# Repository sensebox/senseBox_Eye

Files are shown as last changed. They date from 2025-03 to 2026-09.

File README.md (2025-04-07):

# senseBox Eye
## /examples
Some basic examples to test functionality of the MCU. If youre interested in the AI capabilities of the board you can check out this [image classifier](https://github.com/PaulaScharf/senseBox_Eye-edge_impulse) that I created using edge-impulse.

## /hardware
Contains datasheets and schematics.

## /BSP
Contains configuration for the board support package (which have to be included into the [Arduino core for the ESP32](https://github.com/espressif/arduino-esp32)), UF2 bootloader and circuit python bootloader.

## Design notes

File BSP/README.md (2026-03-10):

Our module is the "ESP32-S3-WROOM-1-N16R8" which has 16MB flash (Quad SPI) and 8MB PSRAM (Octal SPI) on top of 512KB SRAM.

## [arduino-esp32 core](https://github.com/espressif/arduino-esp32)
- `boards.txt` (only contains the segment relevant for senseBox Eye)
- the folder `arduino`

## platformio/espressif32
- the folder `platformio`

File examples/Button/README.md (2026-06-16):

### Pinout
```cpp
#define SW_BUTTON   21
#define BOOT_BUTTON 0
```

# Examples
### sw-button
Print to serial when the "SW"-button is pressed.

### sw-button
Print to serial when the Boot-button is pressed.

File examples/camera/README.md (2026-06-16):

### Pinout
```cpp
#define PWDN_GPIO_NUM  46
#define RESET_GPIO_NUM -1
#define XCLK_GPIO_NUM  15
#define SIOD_GPIO_NUM  4
#define SIOC_GPIO_NUM  5

#define Y9_GPIO_NUM    16 // D7
#define Y8_GPIO_NUM    17 // D6
#define Y7_GPIO_NUM    18 // D5
#define Y6_GPIO_NUM    12 // D4
#define Y5_GPIO_NUM    10 // D3
#define Y4_GPIO_NUM    8  // D2
#define Y3_GPIO_NUM    9  // D1
#define Y2_GPIO_NUM    11 // D0
#define VSYNC_GPIO_NUM 6
#define HREF_GPIO_NUM  7
#define PCLK_GPIO_NUM  13
```

# Tested Camera models
The senseBox Eye comes with an OV2640. But its possible to attach other cameras that use the DVP too.

| model | max resolution | color type | output format | Len Size |
| --- | --- | --- | --- | --- |
| OV2640  | 1600 x 1200 | color | YUV(422/420)/YCbCr422<br>RGB565/555<br>8-bit compressed data<br>8/10-bit Raw RGB data | 1/4" |
| OV7725  | 640 x 480 | color | Raw RGB<br/>GRB 422<br/>RGB565/555/444<br/>YCbCr 422 | 1/4" |
| OV5640  | 2592 x 1944 | color | RAW RGB<br/>RGB565/555/444<br/>CCIR656<br/>YUV422/420<br/>YCbCr422<br/>compression | 1/4" |

Depending on how much ram is already taken up by the rest of the script, the resolution of the camera might have to be reduced to prevent an overflow (additionally it also helps to set the fb_count of the config to 1 instead of higher numbers). So the max resolution can often not be achieved.

# Examples
### CameraWebServer
Default example from the esp32 BSP. Streams camera images over Wifi.

Requires version 3.0.7 of the BSP for face detection and recognition (newer versions dont include the model zoo anymore). Dont forget to adjust the Wifi credentials.

### CameraWebServer_EdgeImpulse
Same as CameraWebServer but with custom edge impulse model instead of face detection. Streaming is broken, only capturing single frames possible.

### camera-display
Continuously print current camera image on the display.

### camera-sd
Capture a single camera image (as JPEG) and save it to sd-card. Requires PSRAM turned on.

### ov7725
Continuously print current camera image on the display. If the "SW"-Button is pressed, capture a single camera image (as RGB565, because ov7725 doesnt natively support JPEG) and save it to sd-card. Requires PSRAM turned on. (Note: WIPES SD-CARD ON STARTUP)

### ov5640
Continuously print current camera image on the display. If the "SW"-Button is pressed, capture a single camera image (as RGB565, because ov5640 doesnt natively support JPEG) and save it to sd-card. The highest resolution achieved with this script is 2560x1600px (4.1MP). Requires PSRAM turned on. (Note: WIPES SD-CARD ON STARTUP)

# esp32-camera
The underlying camera driver used in these examples is [esp32-camera](https://github.com/espressif/esp32-camera). 

It supports the following resolution shorthands:
| key | resolution |
|---|---|
| FRAMESIZE_96X96 | 96x96 |
| FRAMESIZE_QQVGA | 160x120 |
| FRAMESIZE_128X128  | 128x128 |
| FRAMESIZE_QCIF | 176x144 |
| FRAMESIZE_HQVGA | 240x176 |
| FRAMESIZE_240X240  | 240x240 |
| FRAMESIZE_QVGA | 320x240 |
| FRAMESIZE_320X320  | 320x320 |
| FRAMESIZE_CIF | 400x296 |
| FRAMESIZE_HVGA | 480x320 |
| FRAMESIZE_VGA | 640x480 |
| FRAMESIZE_SVGA | 800x600 |
| FRAMESIZE_XGA | 1024x768 |
| FRAMESIZE_HD | 1280x720 |
| FRAMESIZE_SXGA | 1280x1024 |
| FRAMESIZE_UXGA | 1600x1200 |
| **--- 3MP Sensors ---** | 
| FRAMESIZE_FHD | 1920x1080 |
| FRAMESIZE_P_HD | 720x1280 |
| FRAMESIZE_P_3MP | 864x1536 |
| FRAMESIZE_QXGA | 2048x1536 |
| **--- 5MP Sensors ---** |
| FRAMESIZE_QHD | 2560x1440 |
| FRAMESIZE_WQXGA | 2560x1600 |
| FRAMESIZE_P_FHD | 1080x1920 |
| FRAMESIZE_QSXGA | 2560x1920 |
| FRAMESIZE_5MP | 2592x1944 |

The following formats are supported:
| key | pixel format |
|---|---|
| PIXFORMAT_RGB565 | 2BPP / RGB565 |
| PIXFORMAT_YUV422 | 2BPP / YUV422 |
| PIXFORMAT_YUV420 | 1.5BPP / YUV420 |
| PIXFORMAT_GRAYSCALE  | 1BPP / Grayscale |
| PIXFORMAT_JPEG | JPEG / Compressed |
| PIXFORMAT_RGB888 | 3BPP / RGB888 |
| PIXFORMAT_RAW | RAW |
| PIXFORMAT_RGB444 | 3BP2P / RGB444 |
| PIXFORMAT_RGB555 | 3BP2P / RGB555 |

The driver also supports a multitude of camera settings for image capture ([tutorial](https://randomnerdtutorials.com/esp32-cam-ov2640-camera-settings/)).

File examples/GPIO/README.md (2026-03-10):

### Pinout
```cpp
#define IO14 14
#define IO48 48
```

# QWIIC interface
### of the senseBox Eye
```
-4--IO14
-3--IO48
-2--3v3
-1--GND
```

### of the LED-Matrix
```
-4--LED
-3--
-2--3v3
-1--GND
```

### of the water temperature sensor
```
-4--
-3--temperature
-2--3v3
-1--GND
```

### of the soil moisture sensor (smt50)
```
-4--moisture
-3--temperature
-2--3v3
-1--GND
```

# Examples
### analog
Read analog input and print it to serial.

### smt50
Print soil temperature to serial.

### led-matrix
Display a guy with a hat on the LED-matrix.

### scale
Print measured weight using the HX711 to serial.

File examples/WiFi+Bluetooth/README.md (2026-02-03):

The ESP32S3 chip includes both WiFi and Bluetooth functionality. Attach the included antenna to use it. Without the antenna the board might get damaged and the signal strength is drastically reduced.

# Examples
### mac-address
Example script from the ESP32 BSP to print the mac addresses of the MCU to serial.

### wifi-hotspot
Create an access point and host a small website there.

### wifi-connect
Connect to a WiFi access point and continuously print the signal strength. Values can range between 0 (good) and -120 (bad). If the signal is lost try to reconnect.

### ble
Create a service and characteristic and then send and receive values through that characteristics. Can be tested with the "nRF Connect" app for example. 

### openSenseMap
Send data from an HDC1080 sensor to a device on the openSenseMap.

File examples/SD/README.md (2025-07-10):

### Pinout
```cpp
#define VSPI_MISO   40 // DAT
#define VSPI_MOSI   38 // CMD
#define VSPI_SCLK   39 // SCK/CLK
#define VSPI_SS     41 // CS
#define SD_ENABLE   3
#define SD_SW       42 // card detect pin (LOW = card inserted)
```

# Examples
### sd-card-basics
Test basic sd-card functionality and print results to serial.

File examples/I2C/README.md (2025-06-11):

### Pinout
```cpp
#define PIN_QWIIC_SDA 2
#define PIN_QWIIC_SCL 1

Wire.begin(PIN_QWIIC_SDA,PIN_QWIIC_SCL);
```
These pins are both used by the I2C QWIIC interface and the integrated battery sensor (max17048).

# Examples
### i2c-scanner
Standard I2C Scanner based on [this](https://playground.arduino.cc/Main/I2cScanner/).

### vl53l8cx
Print closest distance from vl53l8cx in serial monitor (based on code generated from blockly).

### display
Print the senseBox-bike loading animation and a QR-Code on the display.

### hdc1080
Print temperature and humidity to serial.

### mpu6050
Print acceleration, gyro and temperature to serial.

### sps30
Print PM1.0, PM2.5, PM4.0 and PM10 to serial.

### max17048
Print battery charge measurements from the onboard max17048 sensor to serial and display.

### i2c-chain
Combines display, vl53l8cx, hdc1080, mpu6050 and sps30. Draws the sensor measurements on the display and prints the loop times to serial.

### vl53l8cx-led-matrix
Display distances recorded by the vl53l8cx on the LED-matrix

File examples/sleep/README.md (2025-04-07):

[see sleep mode documentation](https://docs.espressif.com/projects/esp-idf/en/stable/esp32/api-reference/system/sleep_modes.html)

# Examples
### deep-sleep
Go to deep sleep for 2 seconds. Code taken from [here](https://randomnerdtutorials.com/esp32-deep-sleep-arduino-ide-wake-up-sources/).

### light-sleep
Go to light-sleep for 2 seconds, wake up for 2 seconds, go to light-sleep for 2 seconds and so on.

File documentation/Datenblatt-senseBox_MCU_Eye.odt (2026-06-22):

### Datenblatt für die senseBox MCU Eye

#### Allgemeine Informationen

- Modell: senseBox MCU Eye
- Hersteller: Reedu GmbH & Co. KG
- Plattform: Arduino-kompatibel
- Einsatzbereiche: Bildung, Citizen Science, Forschung, Umweltüberwachung, Smart City Anwendungen, Bildverarbeitung, Maschinelles Lernen

#### Technische Spezifikationen

##### Mikrocontroller

- Mikrocontroller: ESP32-S3 (Xtensa LX7 Dual-Core)
- Architektur: 32-Bit
- Taktfrequenz: Bis zu 240 MHz
- Flash-Speicher: 16 MB
- PSRAM: 8 MB
- EEPROM: Emuliert im Flash-Speicher

##### Stromversorgung

- Betriebsspannung: 5V
- Stromversorgung:
  - USB: 5V über USB-C-Anschluss, auch zur Programmierung und Kommunikation
  - Extern: 5V über den VIN-Pin (empfohlene externe Stromquelle: 5V DC)
  - Maximale Spannung: 5V (Achtung: Überschreiten kann die Platine beschädigen)
- Stromaufnahme:
  - Im Durchschnitt ca. 80 mA, abhängig von der aktiven Peripherie und dem Modus (WiFi, Bluetooth)

##### Schnittstellen

- Digitale I/O-Pins: 4 (davon werden standardmäßig 2 als I2C Schnittstelle genutzt)
  - PWM-Pins: Alle digitalen Pins können als PWM-Ausgänge konfiguriert werden
  - Maximaler Strom pro I/O-Pin: 40 mA
- Analoge Eingänge: 4 (12-Bit Auflösung)
  - Analoge Eingangsbereiche: 0 bis 3.3V
- Kommunikationsschnittstellen:
  - I2C: 1 Schnittstelle (fest zugewiesen auf IO2 (SDA) und IO1 (SCL))
- USB: USB-C-Anschluss für Programmierung, Datenübertragung und Stromversorgung
- DVP Kamera Anschluss: Kompatibel mit OV2640 (und ähnlichen Kameras)
- MicroSD-Karten-Slot: Für externe Datenspeicherung (SDIO-Modus)

##### Erweiterungsanschlüsse und Sensor-Integration

- QWIIC-Steckverbinder: Mehrere Ports zur einfachen Integration von Sensoren und -Aktoren (Stecktyp: JST-SH)
- Kompatibilität: Unterstützt diverse Sensoren
- Pin-Kompatibilität: 3.3V kompatibel (die Pins sind nicht 5V tolerant)

##### Physische Eigenschaften

- Abmessungen: 60 mm x 30 mm x 10 mm (L x B x H)
- Gewicht: Ca. 10 Gramm
- Betriebstemperaturbereich: -40°C bis 65°C

##### Eingebettete Funktionen

- Bootloader: Arduino-kompatibel, ermöglicht einfache Programmierung über die Arduino-IDE und andere Entwicklungsumgebungen wie ESP-IDF
- ADC: 12-Bit A/D-Wandler für analoge Eingänge, ermöglicht präzise Messungen
- Low-Power-Modus: Verschiedene Energiesparmodi, um den Stromverbrauch zu minimieren

#### Anwendungsbereiche

- Bildung: Ideal für den Unterricht in Elektronik, Programmierung, Maschinellem Lernen und Umweltsensorik, inklusive praktischer Projekte und Experimente
- Citizen Science: Ermöglicht Bürgerwissenschaftlern, Umweltdaten zu sammeln und zu analysieren, z.B. Luftqualität, Wetterdaten
- Umweltüberwachung: In stationären und mobilen Umweltsensorplattformen zur Überwachung von Temperatur, Luftfeuchtigkeit, Licht, UV-Strahlung und mehr
- Forschung: Unterstützt wissenschaftliche Projekte durch präzise Datenerfassung und flexible Integration von Sensoren und Aktoren
- Smart City: Integration in Smart City Projekte zur Überwachung von Umweltparametern, Verkehrsdaten und zur Steuerung städtischer Infrastrukturen
- Bildverarbeitung: Eignet sich für Projekte im Bereich der computergestützten Bildanalyse.

#### Sicherheits- und Nutzungsrichtlinien

- Elektrische Sicherheit:
  - Maximale Eingangsspannung: Vin-Pin nicht über 5V versorgen, da die Pins nur für 3.3V ausgelegt sind
  - Kurzschlussvermeidung: Vorsichtiger Umgang mit den Pins und Verbindungen zur Vermeidung von Kurzschlüssen
- Wärmemanagement:
  - Belüftung: Sorgen Sie für ausreichende Kühlung und Belüftung, insbesondere bei hoher Rechenlast oder Außeneinsatz bei hohen Temperaturen.
- Umgang mit empfindlichen Komponenten:
  - Elektrostatische Entladung (ESD): Verwenden Sie antistatische Armbänder und ESD-Schutzmatten beim Umgang mit der Platine, um Beschädigungen zu vermeiden.
- Umweltschutz:
  - Feuchtigkeitsschutz: Vermeiden Sie den Einsatz in extrem feuchten Umgebungen oder unter Wasser ohne entsprechende Schutzgehäuse.

#### Verpackung und Lieferung

- Lieferumfang: senseBox MCU Eye, OV2640
- Verpackung: Antistatische Verpackung zum Schutz vor elektrostatischen Entladungen, robuste Verpackung für sicheren Transport

#### Hinweise und Empfehlungen

- Software & Programmierung:
  - Arduino IDE: Unterstützt die Entwicklung von Anwendungen mit ESP-IDF und der Arduino-IDE, inklusive Bibliotheken für Sensoren und Aktoren
  - Online-Ressourcen: Umfangreiche Dokumentation, Tutorials und Forenbeiträge sind verfügbar, um Benutzer bei der Entwicklung und Implementierung von Projekten zu unterstützen
- Erweiterungsmöglichkeiten:
  - Sensoren: Breite Palette an kompatiblen Sensoren und Aktoren verfügbar, z.B. für Wetterüberwachung, Luftqualität, Wassersensorik
  - Kommunikationsmodule: WiFi, Bluetooth, & LoRa integriert

Hinweis: Dieses Datenblatt bietet eine umfassende Übersicht über die technischen Spezifikationen, Funktionen und Anwendungsmöglichkeiten der senseBox MCU Eye. Für spezifische Anwendungen und detaillierte technische Informationen wird empfohlen, die vollständige technische Dokumentation sowie die Benutzerhandbücher zu konsultieren.

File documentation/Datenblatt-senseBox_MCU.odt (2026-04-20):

### Datenblatt für die senseBox MCU

#### Allgemeine Informationen

- Modell: senseBox MCU
- Hersteller: senseBox
- Plattform: Arduino-kompatibel
- Einsatzbereiche: Bildung, Citizen Science, Forschung, Umweltüberwachung, Smart City Anwendungen

#### Technische Spezifikationen

##### Mikrocontroller

- Mikrocontroller: Atmel ATmega2560
- Architektur: 8-Bit AVR RISC
- Taktfrequenz: 16 MHz
- Flash-Speicher: 256 KB (8 KB reserviert für den Bootloader)
- SRAM: 8 KB
- EEPROM: 4 KB

##### Stromversorgung

- Betriebsspannung: 5V (Versorgungsspannung für alle Pins)
- Stromversorgung:
  - USB: 5V über USB-B-Anschluss, auch zur Programmierung und Kommunikation
  - Extern: 7-12V über DC-Netzteilanschluss (Barrel Jack) oder Vin-Pin
  - Maximale Spannung: 20V (Achtung: Überschreiten kann die Platine beschädigen)
- Stromaufnahme:
  - Abhängig von der Anzahl und Art der angeschlossenen Komponenten und Sensoren

##### Schnittstellen

- Digitale I/O-Pins: 54, davon 15 als PWM-Ausgänge nutzbar
  - PWM-Pins: 2 bis 13, 44 bis 46
  - Maximaler Strom pro I/O-Pin: 40 mA
  - Maximaler Strom für alle I/O-Pins zusammen: 200 mA
- Analoge Eingänge: 16 (10-Bit Auflösung)
  - Analoge Eingangsbereiche: 0 bis 5V (Standard), einstellbar auf 1.1V (interner Referenzspannung) oder externe Referenz
  - Analoge Referenzspannung: AREF Pin für externe Referenzspannungen
- Kommunikationsschnittstellen:
  - UART: 4 serielle Schnittstellen für serielle Kommunikation (Serial, Serial1, Serial2, Serial3)
  - I2C: 1 Schnittstelle (fest zugewiesen auf A4 (SDA) und A5 (SCL))
  - SPI: 1 Schnittstelle (fest zugewiesen auf digitalen Pins 50 (MISO), 51 (MOSI), 52 (SCK), 53 (SS))
- USB: USB-B-Anschluss für Programmierung und serielle Kommunikation, Unterstützung von USB 2.0
- SD-Karten-Slot: MicroSD-Kartenleser für externe Datenspeicherung (SDIO-Modus)

##### Erweiterungsanschlüsse und Sensor-Integration

- Grove-Steckverbinder: Mehrere Ports für den einfachen Anschluss von Grove-Sensoren und -Aktoren (z.B. Grove Temperature & Humidity Sensor, Grove Air Quality Sensor)
- Kompatibilität: Unterstützt Arduino Shields, die für den Mega 2560 Formfaktor ausgelegt sind, z.B. Ethernet Shield, WiFi Shield, GSM Shield

##### Physische Eigenschaften

- Abmessungen: 84 mm x 55 mm x 12 mm (L x B x H)
- Gewicht: Ca. 35 Gramm
- Betriebstemperaturbereich: 0°C bis 70°C
- Lagerungstemperaturbereich: -20°C bis 85°C

##### Eingebettete Funktionen

- Bootloader: Arduino-kompatibel, ermöglicht einfache Programmierung über die Arduino-IDE und USB-Verbindung
- RTC: Optional über Zusatzmodule (Real Time Clock) zur Zeitstempelung von Daten
- Watchdog-Timer: Integriert, um das System bei Fehlfunktionen neu zu starten und erhöhte Systemsicherheit zu gewährleisten
- ADC: 10-Bit A/D-Wandler für analoge Eingänge, ermöglicht präzise Messungen

#### Anwendungsbereiche

- Bildung: Ideal für den Unterricht in Elektronik, Programmierung und Umweltsensorik, inklusive praktischer Projekte und Experimente
- Citizen Science: Ermöglicht Bürgerwissenschaftlern, Umweltdaten zu sammeln und zu analysieren, z.B. Luftqualität, Wetterdaten
- Umweltüberwachung: In stationären und mobilen Umweltsensorplattformen zur Überwachung von Temperatur, Luftfeuchtigkeit, Licht, UV-Strahlung und mehr
- Forschung: Unterstützt wissenschaftliche Projekte durch präzise Datenerfassung und flexible Integration von Sensoren und Aktoren
- Smart City: Integration in Smart City Projekte zur Überwachung von Umweltparametern, Verkehrsdaten und zur Steuerung städtischer Infrastrukturen

#### Sicherheits- und Nutzungsrichtlinien

- Elektrische Sicherheit:
  - Überspannungsschutz: Vermeiden Sie Spannungen über 12V an den Vin-Pin, um Schäden an der Hardware zu vermeiden.
  - Kurzschlussvermeidung: Stellen Sie sicher, dass keine Kurzschlüsse zwischen den I/O-Pins und anderen leitenden Materialien auftreten.
- Wärmemanagement:
  - Belüftung: Sorgen Sie für ausreichende Belüftung, insbesondere bei hoher Stromaufnahme oder Außeneinsatz bei hohen Temperaturen.
- Umgang mit empfindlichen Komponenten:
  - Elektrostatische Entladung (ESD): Verwenden Sie antistatische Armbänder und ESD-Schutzmatten beim Umgang mit der Platine, um Beschädigungen zu vermeiden.
- Umweltschutz:
  - Feuchtigkeitsschutz: Vermeiden Sie den Einsatz in extrem feuchten Umgebungen oder unter Wasser ohne entsprechende Schutzgehäuse.

#### Verpackung und Lieferung

- Lieferumfang: senseBox MCU-Platine, USB-Kabel, Schnellstartanleitung
- Verpackung: Antistatische Verpackung zum Schutz vor elektrostatischen Entladungen, robuste Verpackung für sicheren Transport

#### Hinweise und Empfehlungen

- Software & Programmierung:
  - Arduino IDE: Unterstützt die Entwicklung von Anwendungen mit der Arduino-IDE, inklusive Bibliotheken für Sensoren und Aktoren
  - Online-Ressourcen: Umfangreiche Dokumentation, Tutorials und Forenbeiträge sind verfügbar, um Benutzer bei der Entwicklung und Implementierung von Projekten zu unterstützen
- Erweiterungsmöglichkeiten:
  - Sensoren: Breite Palette an kompatiblen Sensoren und Aktoren verfügbar, z.B. für Wetterüberwachung, Luftqualität, Wassersensorik
  - Kommunikationsmodule: Unterstützung für WiFi, Bluetooth, GSM, LoRa durch Zusatzmodule und Shields

Hinweis: Dieses Datenblatt bietet eine umfassende Übersicht über die technischen Spezifikationen, Funktionen und Anwendungsmöglichkeiten der senseBox MCU. Für spezifische Anwendungen und detaillierte technische Informationen wird empfohlen, die vollständige technische Dokumentation sowie die Benutzerhandbücher zu konsultieren.

### Anwendungsbeispiel: Überwachung der Luftqualität in städtischen Gebieten ohne Gassensor

#### Projektziel

Das Ziel dieses Projekts ist die Überwachung der Luftqualität in einem städtischen Gebiet, insbesondere durch die Erfassung von Feinstaubkonzentrationen (PM2.5 und PM10), Temperatur, Luftfeuchtigkeit und Luftdruck. Dies soll dazu beitragen, Umwelt- und Gesundheitsinformationen für die Bevölkerung bereitzustellen und datenbasierte Entscheidungen zu unterstützen.

#### Komponenten und Ausstattung

- senseBox MCU: Zentrale Steuerungseinheit zur Datenerfassung und -verarbeitung.
- Feinstaubsensor (z.B. SDS011): Misst die Konzentration von Feinstaubpartikeln (PM2.5 und PM10) in der Luft.
- Temperatur- und Luftfeuchtigkeitssensor (z.B. HDC1080): Erfasst die Umgebungstemperatur und relative Luftfeuchtigkeit.
- Luftdrucksensor (z.B. DPS310): Misst den atmosphärischen Luftdruck.
- Grove-Verbindungskabel: Zur einfachen Verbindung der Sensoren mit der senseBox MCU.
- MicroSD-Karte: Zur Speicherung der gesammelten Daten.
- Optional: WLAN-Modul (z.B. ESP8266): Ermöglicht die drahtlose Übertragung der Daten an eine zentrale Datenbank oder Cloud.

#### Projektaufbau

1. Installation und Montage:
  - Die senseBox MCU und die Sensoren werden in einem wetterfesten Gehäuse montiert und an einem repräsentativen Ort im städtischen Gebiet installiert. Orte mit hohem Verkehrsaufkommen oder in der Nähe von Industriegebieten sind besonders relevant.
2. Sensorintegration und Kalibrierung:
  - Die Sensoren werden über Grove-Kabel an die senseBox MCU angeschlossen. Die Programmierung erfolgt mithilfe der Arduino-IDE unter Verwendung spezifischer Bibliotheken für die Sensoren.
  - Eine Kalibrierung der Sensoren, insbesondere des Feinstaubsensors, wird durchgeführt, um genaue und zuverlässige Messungen zu gewährleisten.
3. Datenaufzeichnung und -speicherung:
  - Die erfassten Daten (PM2.5, PM10, Temperatur, Luftfeuchtigkeit, Luftdruck) werden in regelmäßigen Intervallen (z.B. alle 5 Minuten) auf der MicroSD-Karte gespeichert. Die Speicherung umfasst Zeitstempel, um die Datenanalyse zu ermöglichen.
  - Optional können die Daten zusätzlich über WLAN an eine zentrale Datenbank gesendet werden, um eine Echtzeitüberwachung zu ermöglichen.
4. Datenübertragung und -verarbeitung:
  - Bei Verwendung eines WLAN-Moduls werden die Daten kontinuierlich an einen Server übertragen, wo sie gespeichert und verarbeitet werden können.
  - Die Daten werden visualisiert, um die Entwicklung der Luftqualität über die Zeit hinweg darzustellen. Dies kann durch Diagramme, Tabellen oder interaktive Karten geschehen.
5. Öffentliche Information und Sensibilisierung:
  - Eine Webplattform oder eine mobile App kann eingerichtet werden, um die Öffentlichkeit über die aktuelle Luftqualität zu informieren. Wichtige Daten wie Feinstaubkonzentration, Temperatur und Luftdruck sind zugänglich.
  - Benachrichtigungen oder Warnungen werden ausgegeben, wenn bestimmte Schwellenwerte, insbesondere für Feinstaub, überschritten werden, um gesundheitliche Risiken zu kommunizieren.

#### Nutzen und Vorteile

- Gesundheitsförderung: Die Bevölkerung wird über die aktuelle Luftqualität informiert, was insbesondere für empfindliche Gruppen wie Kinder, ältere Menschen und Personen mit Atemwegserkrankungen wichtig ist.
- Datenbasierte Entscheidungen: Die erhobenen Daten unterstützen städtische Planer und Behörden bei der Entwicklung von Maßnahmen zur Verbesserung der Luftqualität, wie z.B. der Begrünung von Flächen oder der Verkehrsregulierung.
- Bildungszwecke: Die gesammelten Daten können in Schulen und Universitäten genutzt werden, um die Bedeutung von Umweltüberwachung und Luftqualität zu lehren.

#### Herausforderungen und Lösungen

- Datengenauigkeit: Um die Qualität der Daten sicherzustellen, müssen die Sensoren regelmäßig überprüft und gewartet werden. Kalibrierungsprozeduren sollten regelmäßig durchgeführt werden.
- Wetterbedingungen: Bei extremen Wetterbedingungen muss die senseBox in einem geeigneten Gehäuse geschützt werden, um die Sensoren vor Beschädigung zu schützen.

Dieses Anwendungsbeispiel zeigt, wie die senseBox MCU ohne Gassensoren effektiv zur Überwachung und Analyse der Luftqualität in städtischen Gebieten genutzt werden kann, um wichtige Umwelt- und Gesundheitsdaten bereitzustellen.

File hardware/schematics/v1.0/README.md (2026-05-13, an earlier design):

In these schematics the sd-card is missing the CS-Pin. The sd-card doesnt work.

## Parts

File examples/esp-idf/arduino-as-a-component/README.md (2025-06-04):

# arduino-as-a-component
The esp-idf allows to include the esp32-arduino framework. This allows one to use arduino libraries in the esp-idf. 

In this example the Adafruit Neopixel library is included. Once flashed, the RGB-LED onboard the senseBox Eye should go through a rainbow cycle of colors.

Before building you need to run the following commands in this folder:
```
mkdir -p components && \
cd components && \
git clone https://github.com/espressif/arduino-esp32.git arduino
```

The Adafruit_Neopixel library then has to be copied into `components/arduino/libraries`. The `components/arduino/CMakeLists.txt` now has to be adjusted. After the line `set(ARDUINO_ALL_LIBRARIES` add `Adafruit_NeoPixel`. Furthermore the following lines have to be added:
```
set(ARDUINO_LIBRARY_Adafruit_NeoPixel_SRCS libraries/Adafruit_NeoPixel/Adafruit_NeoPixel.cpp
  libraries/Adafruit_NeoPixel/esp.c 
  libraries/Adafruit_NeoPixel/esp8266.c 
  libraries/Adafruit_NeoPixel/kendyte_k210.c)
```
And lastly the includedirs have to be adjusted like so: `set(includedirs variants/${CONFIG_ARDUINO_VARIANT}/ cores/esp32/ ${ARDUINO_LIBRARIES_INCLUDEDIRS} libraries/Adafruit_NeoPixel)`.

When building I had problems with the i2c-slave (I fixed one line and commented another one out). I also had to make a tiny adjustment to the neopixel library code (the error message will tell you what to do).

[This wiki page](https://docs.espressif.com/projects/arduino-esp32/en/latest/esp-idf_component.html) gives more details about including arduino as a component.

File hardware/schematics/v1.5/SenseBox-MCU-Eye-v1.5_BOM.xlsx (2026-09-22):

 |  |  | senseBox MCU Eye v1.5
Item # | *Designator | *Qty | Manufacturer | *Mfg Part # | Description / Value | *Package/Footprint | Type | Your Instructions / Notes
1 | C1, C2, C4, C15, C16, C23, C24 | 7 |  | CL05A475MP5NRNC | CAP CER 4.7UF 10V X5R 0402 | C0402 | SMD
2 | C3, C5, C7, C8, C9, C10, C13, C14, C18, C19, C20, C21, C22, C29 | 14 |  | GRM155R71C104KA88D | CAP CER 100NF 16V X7R 0402 | C0402 | SMD
3 | C6 | 1 |  | GRM158R61A226ME15J | CAP CER 22UF 10V X5R 0402 | C0402 | SMD
4 | C11 | 1 |  | CL05A106MQ5NUNC | CAP CER 10UF 6.3V X5R 0402 | C0402 | SMD
5 | C12 | 1 |  | CL05A106MQ5NUNC | CAP CER 10UF 6.3V X5R 0402 | C0402 | SMD
6 | C17, C28 | 2 |  | GRM155R61C105KA12D | CAP CER 1UF 16V X5R 0402 | C0402 | SMD
7 | C25, C26, C27 | 3 |  | GRM155R61A225KE95D | CAP CER 2.2UF 10V X5R 0402 | C0402 | SMD
8 | C30, C31 | 2 |  | GRM21BR60J226ME39L | CAP CER 22UF 6.3V X5R 0805 | 0805N | SMD
9 | C32, C33 | 2 |  | GRM188R61A475KE15D | CAP CER 4.7UF 10V X5R 0603 | 0603N | SMD
10 | D1 | 1 | Worldsemi | WS2812B-2020 | Addressable RGB LED (integrated driver), 2020 package | WS2812_2020 | SMD
11 | D2 | 1 | Texas Instruments | LM66200DRLR | Ideal diode / power mux controller | SOT-5X3 | SMD
12 | D3 | 1 | Infineon Technologies | ESD5V3U2U-03F-E6327 | Uni-directional TVS/ESD protection diode, 5.3V, 0.4pF | SOT723 | SMD
13 | D4 | 1 |  | LTST-C190KRKT | LED, red, 0603 | 0603N | SMD
14 | D5, D6 | 2 |  | 1PS79SB40,115 | General-purpose Schottky diode, SOD523 | SOD523 | SMD
15 | D7 | 1 |  | LTST-C190KGKT | LED, green, 0603 | 0603N | SMD
16 | IC1 | 1 | Espressif Systems | ESP32-S3-WROOM-1-N16R8 | WiFi/BLE MCU module, 16MB flash / 8MB PSRAM | ESP32-S3-WROOM-1 | SMD
17 | IC2 | 1 | Amphenol Communications Solutions (FCI) | F34G-1A7Q1-E8C24 | FPC connector, right-angle SMD, 24-pos, 0.5mm pitch | WE-CHIP_FPC24-0.5-CAM | SMD
18 | IC3 | 1 | Microchip | MCP73831T-2ACI/OT | Li-Ion/Li-Po linear charge management controller | SOT23-5 | SMD
19 | IC4 | 1 |  | RFM95W-868S2 | LoRa transceiver module, 868MHz (SX1276) | RFM9X | SMD
20 | IC5 | 1 | Diodes Incorporated | AP2127N-2.8TRG1 | 150mA CMOS LDO regulator, 2.8V | SOT23 | SMD
21 | IC6 | 1 | Diodes Incorporated | AP2127N-1.5TRG1 | 150mA CMOS LDO regulator, 1.5V | SOT23 | SMD
22 | IC7 | 1 | Texas Instruments | REG710NA-5 | 150mA low-Iq LDO regulator, 5V | SOT23-6 | SMD
23 | IC8 | 1 | Analog Devices (Maxim) | MAX17048G+T10 | 1-cell fuel gauge IC, UDFN8 2x2mm | UDFN8_2020 | SMD
24 | IC9 | 1 | Richtek | RP602Z330C-E2-F | Buck converter IC, WLCSP | WLCSP-20-P1 | SMD
25 | IC10 | 1 | TDK InvenSense | ICM-20948 | 9-axis IMU (accel/gyro/mag), QFN24 3x3mm | QFN24-3X3 | SMD
26 | IC11 | 1 |  | AP2127N-1.8TRG1 | 150mA CMOS LDO regulator, 1.8V | SOT23 | SMD
27 | J1 | 1 | Hroparts | TYPE-C-31-M-12 | USB Type-C receptacle, 12-pin SMD | USB-C-S | SMD
28 | J2 | 1 |  | U.FL-R-SMT-1(10) | U.FL RF coax receptacle, PCB mount, 50 ohm | U.FL | SMD
29 | J3 | 1 | JST | S2B-PH-SM4-TB | 2-pos PH-series SMD header, top entry | JST_S2B-PH-SM4-TB | SMD
30 | J4, J6 | 2 | JST | SM04B-SRSS-TB | 4-pos SR-series SMD header, top entry | JST_SM04B-SRSS-TB | SMD
31 | J5 | 1 | JST | SM02B-SRSS-TB | 2-pos SR-series SMD header, top entry | JST_SM02B-SRSS-TB | SMD
32 | L2 | 1 |  | SRN5040TA-1R0M | INDUCTOR SHIELDED PWR 1UH SMD | 5040 | SMD
33 | Q2 | 1 | Nexperia | PMV48XP,215 | P-channel MOSFET, -20V | SOT23 | SMD
34 | R1, R13, R14 | 3 |  | RC0402FR-07100KL | RES 100K OHM 1% 0402 | C0402 | SMD
35 | R2, R3, R4, R37 | 4 |  | RC0402JR-070RL | RES 0 OHM JUMPER 0402 | C0402 | SMD
36 | R5, R6, R7, R15, R17, R20, R26, R27, R28, R29, R44, R45 | 12 |  | RC0402FR-0710KL | RES 10K OHM 1% 0402 | C0402 | SMD
37 | R8, R16, R33, R34 | 4 |  | RC0402FR-0733RL | RES 33 OHM 1% 0402 | C0402 | SMD
38 | R9, R10, R23, R24 | 4 |  | RC0402FR-074K7L | RES 4.7K OHM 1% 0402 | C0402 | SMD
39 | R11 | 1 |  | RC0402FR-072KL | RES 2K OHM 1% 0402 | C0402 | SMD
40 | R12, R18 | 2 |  | RC0402FR-071KL | RES 1K OHM 1% 0402 | C0402 | SMD
41 | R30, R31, R48, R50 | 4 |  | RC0402FR-075K1L | RES 5.1K OHM 1% 0402 | C0402 | SMD
42 | R39 | 1 |  | RC0402FR-07330RL | RES 330 OHM 1% 0402 | C0402 | SMD
43 | SD1 | 1 | Amphenol FCI | 10067099-400LF | microSD card socket, push-push | SD_47309XXXX | SMD
44 | SW1, SW2, SW3 | 3 | E-Switch | TL3305AF160QG | SMD tactile push-button switch, TL3305 series | TL3305 | SMD
45 | SW4 | 1 | Nidec Components | CUS-22TB | SMD slide switch, DPDT, 0.3A/4VDC | CUS22B | SMD
46 | T8 | 1 | Nexperia | BSS138PS,115 | N-channel MOSFET, 60V | SOT363 | SMD

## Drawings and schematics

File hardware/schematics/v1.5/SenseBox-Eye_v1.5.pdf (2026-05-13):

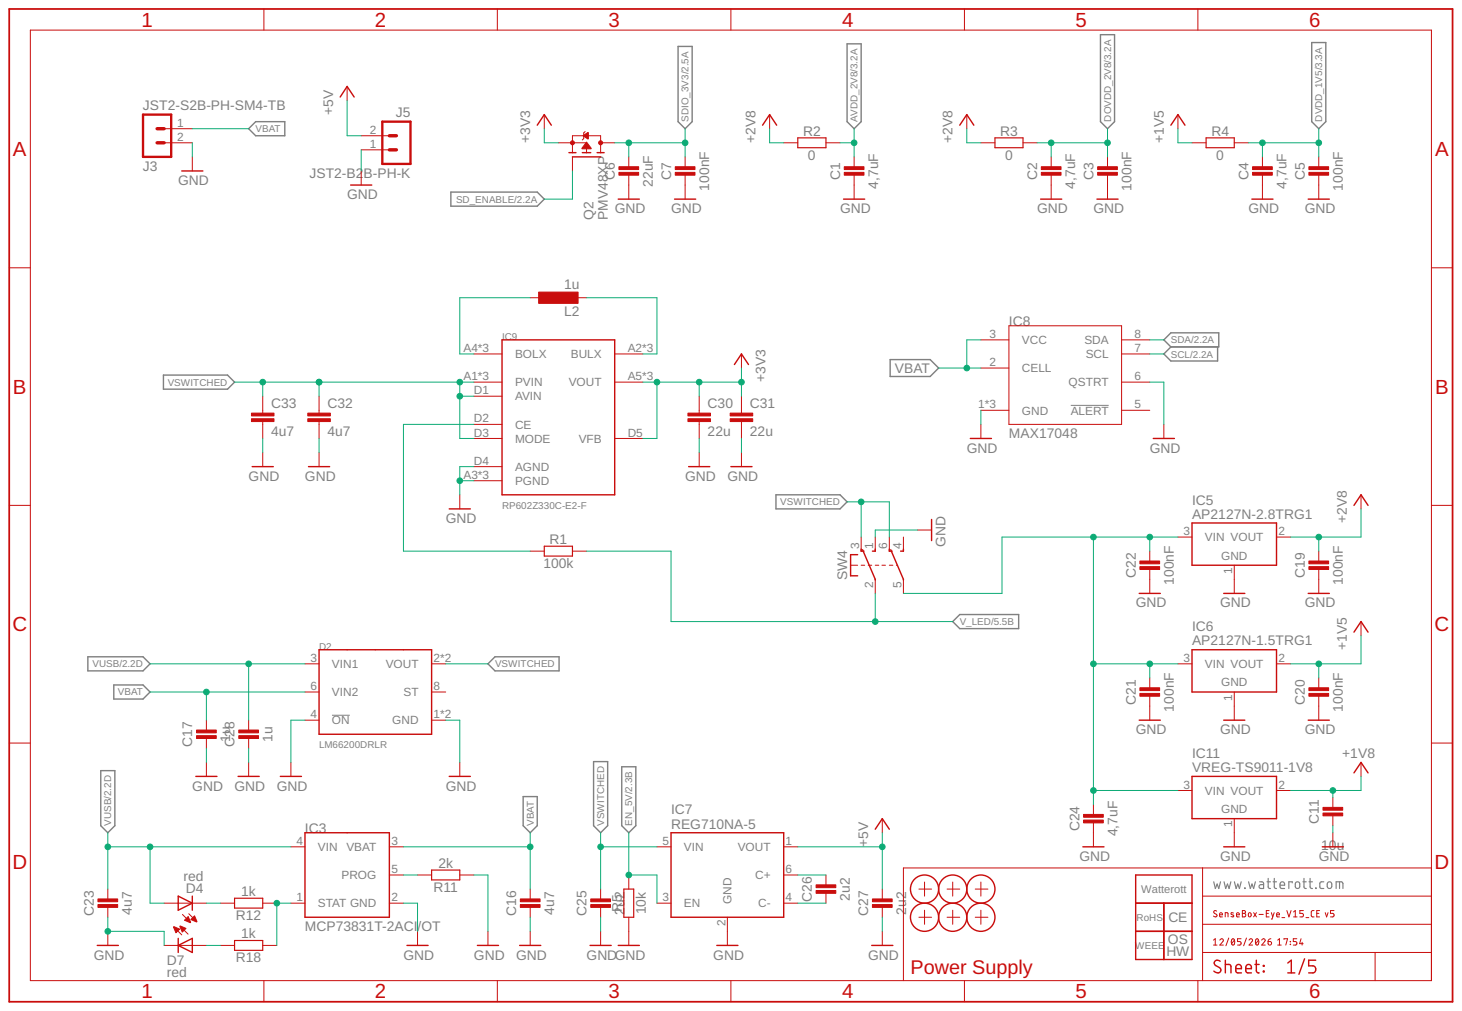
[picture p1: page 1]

red 1k | 2k

Power Supply

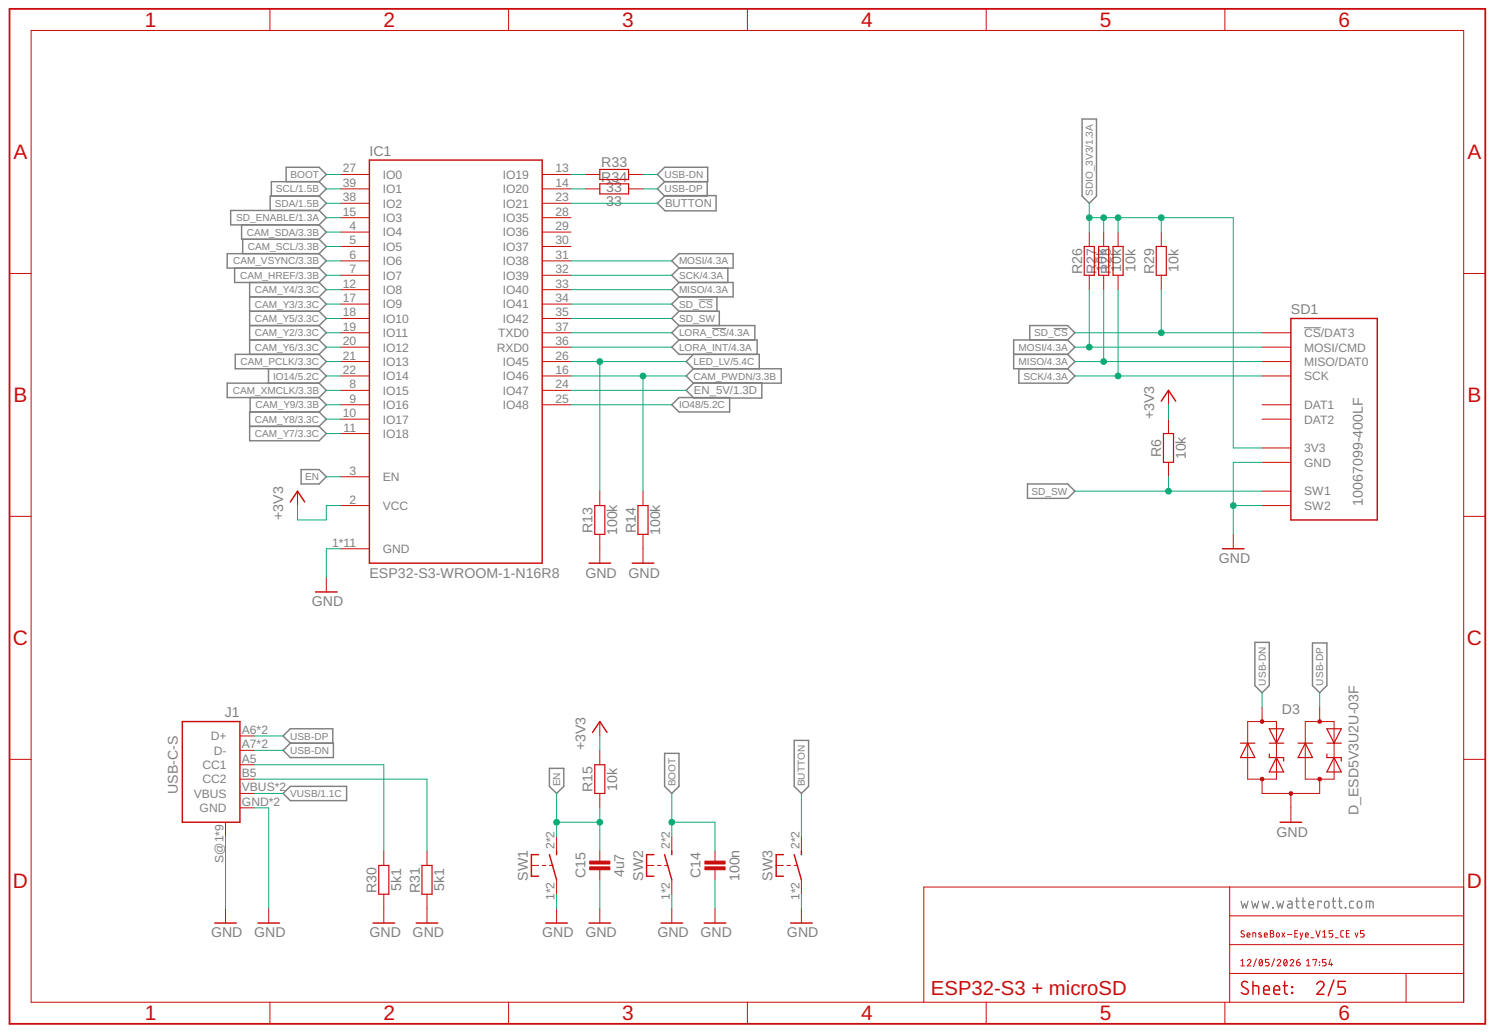
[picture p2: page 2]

10k 10k 10k 10k D_ESD5V3U2U-03F 5k1 5k1 GND GND GND GND 3333 100n 4u7 +3V3 GND GND GND GND GND GND GND GND 100k 100k GND GND 10k +3V3 10k +3V3 IC1 ESP32-S3-WROOM-1-N16R8 IO36 29 IO39 32 IO38 31 IO35 28 IO37 30 IO40 33 IO48 25 IO14 22 IO12 20 IO13 21 IO9 17 IO10 18 IO11 19 IO47 24 IO1 39 IO3 15 IO21 23 IO19 13 IO18 11 IO5 5 IO17 10 IO16 9 IO4 4 IO0 27 IO2 38 IO15 8 IO8 12 IO7 7 IO6 6 EN 3 VCC 2 GND 1*11 IO41 34 IO42 35 IO45 26 IO46 16 TXD0 37 RXD0 36 IO20 14 SD1 10067099-400LF DAT2 CS/DAT3 MOSI/CMD 3V3 SCK GND MISO/DAT0 DAT1 SW1 SW2 R26 R27 R28 R29 J1 USB-C-SD+ A6*2 D- A7*2 VBUS VBUS*2 GND GND*2 S@1*9 CC1 A5 CC2 B5 D3 R30 R31 R33 R34 C14 C15 SW3 1*2 2*2 SW1 1*2 2*2 SW2 1*2 2*2 R13 R14 R15 R6 CAM_SDA/3.3B CAM_SCL/3.3B CAM_HREF/3.3B CAM_Y4/3.3C CAM_Y3/3.3C CAM_Y5/3.3C CAM_Y2/3.3C CAM_Y6/3.3C CAM_PCLK/3.3C BUTTON BUTTON CAM_XMCLK/3.3B CAM_Y9/3.3B CAM_Y8/3.3C CAM_Y7/3.3C CAM_PWDN/3.3B SD_ENABLE/1.3A SCL/1.5B CAM_VSYNC/3.3B MOSI/4.3A MOSI/4.3A MISO/4.3A MISO/4.3A SCK/4.3A SCK/4.3A SDIO_3V3/1.3A SD_CS SD_CS USB-DP USB-DP USB-DP USB-DN USB-DN USB-DN VUSB/1.1C LORA_CS/4.3A LORA_INT/4.3A BOOT BOOTEN EN SDA/1.5B LED_LV/5.4C SD_SW SD_SW IO14/5.2C IO48/5.2C EN_5V/1.3D ESP32-S3 + microSD ABCD 1 2 3 4 5 6 ABCD 1 2 3 4 5 6

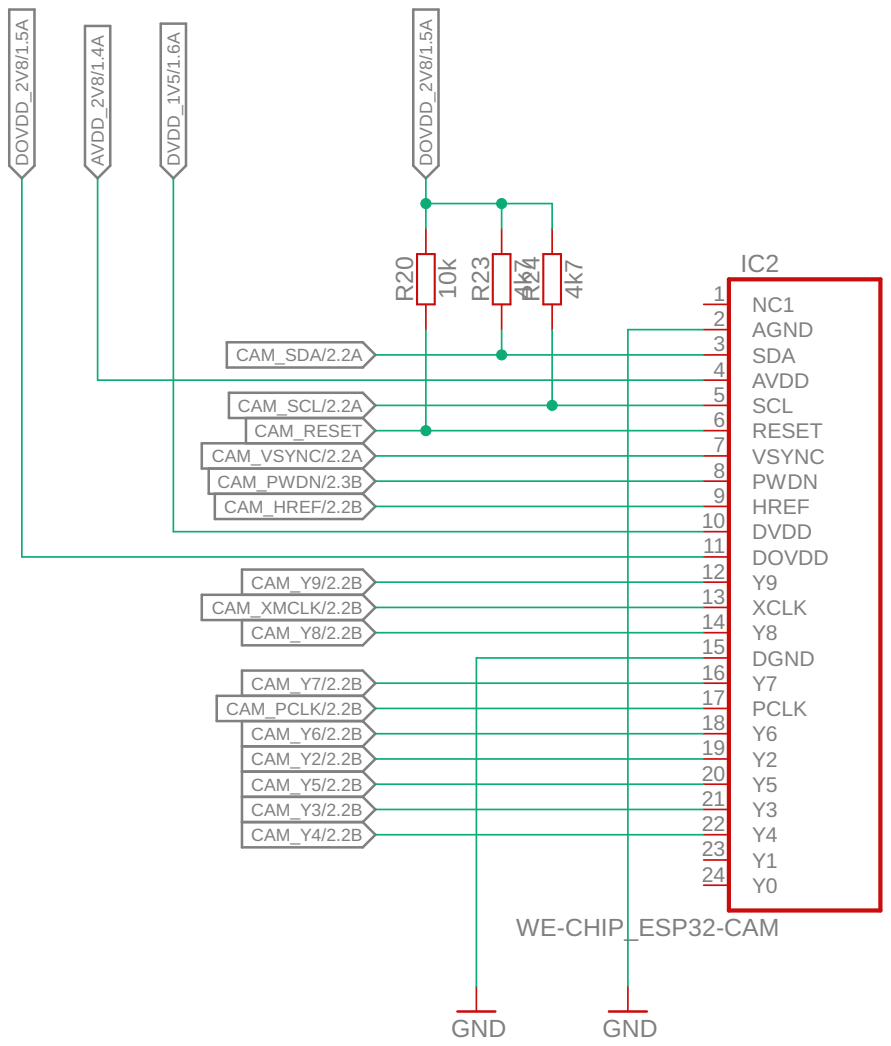
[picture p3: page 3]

10k 4k7 4k7 GND GND WE-CHIP_ESP32-CAM R20 R23 R24IC2AGND 2 AVDD 4 DGND 15 DOVDD 11 DVDD 10 HREF 9 NC1 1 PCLK 17 PWDN 8 RESET 6 SCL 5 SDA 3 VSYNC 7 XCLK 13 Y0 24 Y1 23 Y2 19 Y3 21 Y4 22 Y5 20 Y6 18 Y7 16 Y8 14 Y9 12 CAM_SDA/2.2A CAM_SCL/2.2A AVDD_2V8/1.4A CAM_RESET CAM_VSYNC/2.2A CAM_PWDN/2.3B CAM_HREF/2.2B DVDD_1V5/1.6A CAM_Y9/2.2B CAM_XMCLK/2.2B CAM_Y8/2.2B CAM_Y7/2.2B CAM_Y6/2.2B CAM_Y2/2.2B CAM_Y5/2.2B CAM_Y3/2.2B CAM_Y4/2.2B DOVDD_2V8/1.5A DOVDD_2V8/1.5A CAM_PCLK/2.2B Kamera ABCD 1 2 3 4 5 6 ABCD 1 2 3 4 5 6

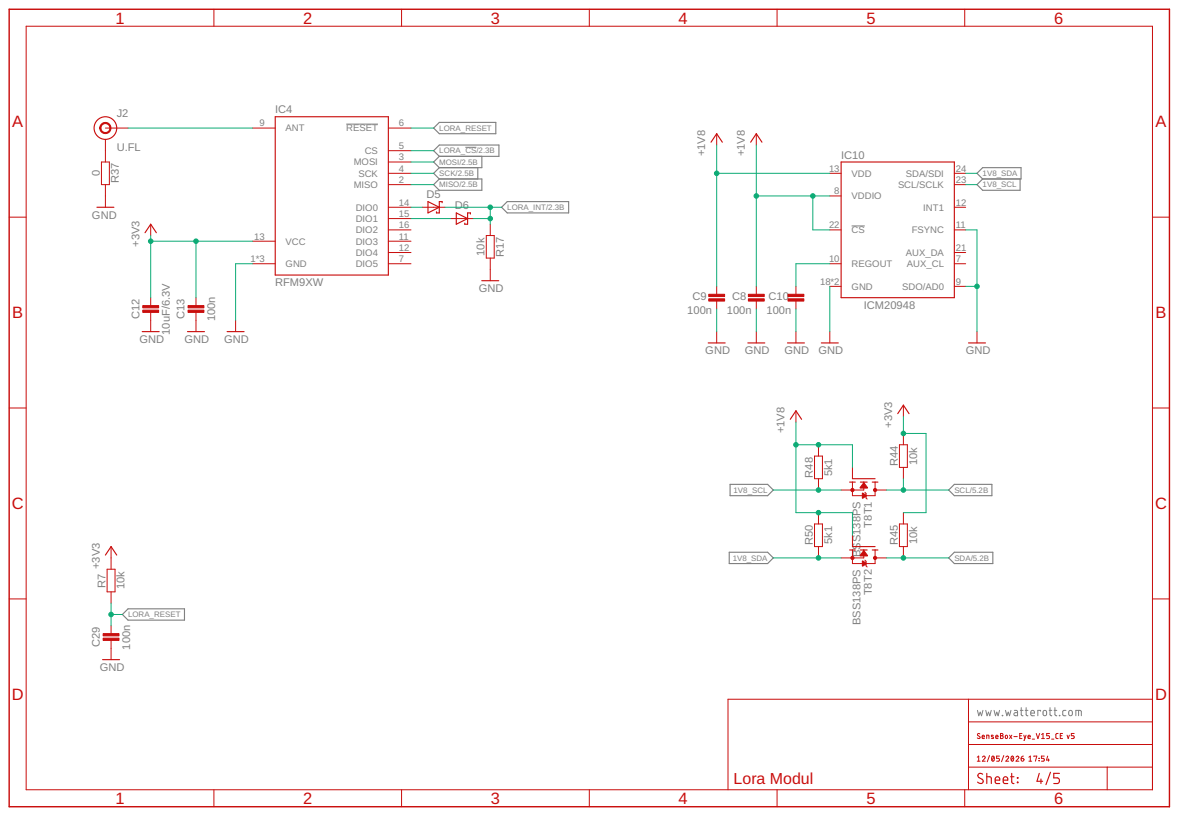
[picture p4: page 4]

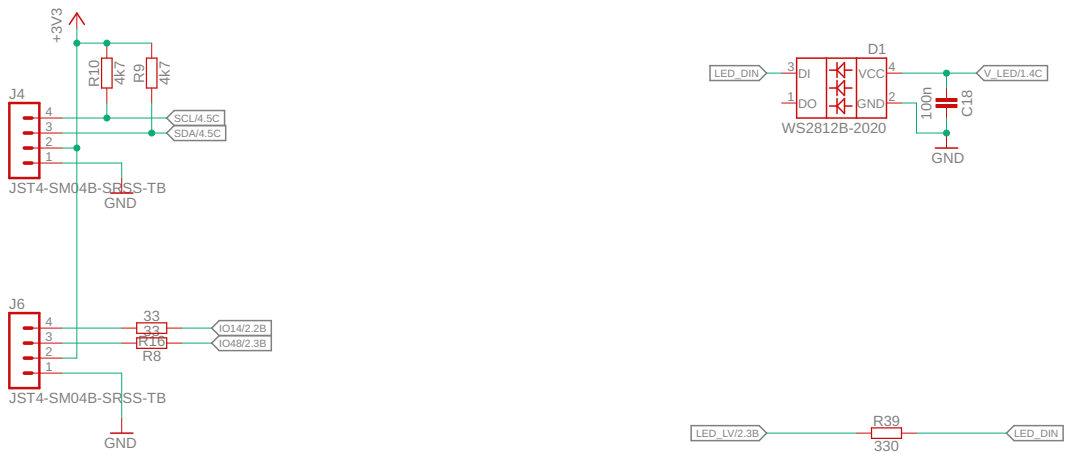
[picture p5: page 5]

33 | IO14/2.2B
R16 | IO48/2.3B

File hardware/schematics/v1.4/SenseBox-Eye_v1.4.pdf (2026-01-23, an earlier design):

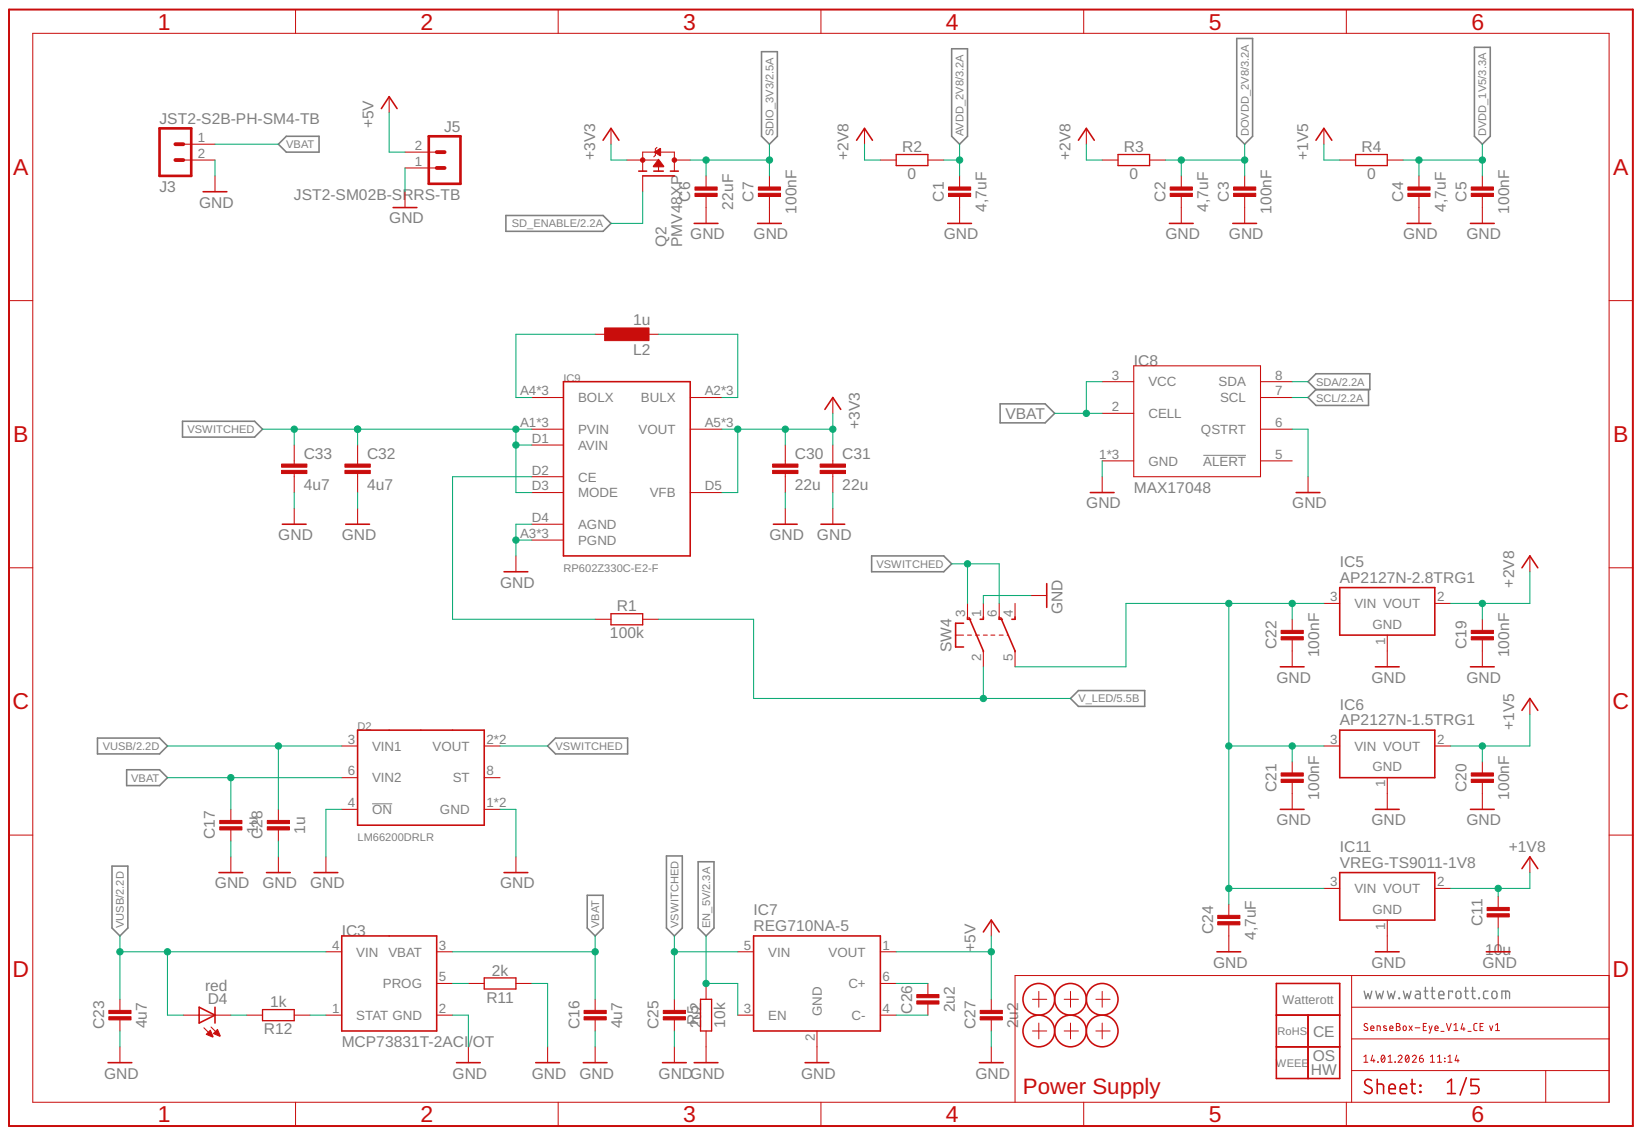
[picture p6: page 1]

red 1k | 2k

WEEE Watterott RoHS

Power Supply

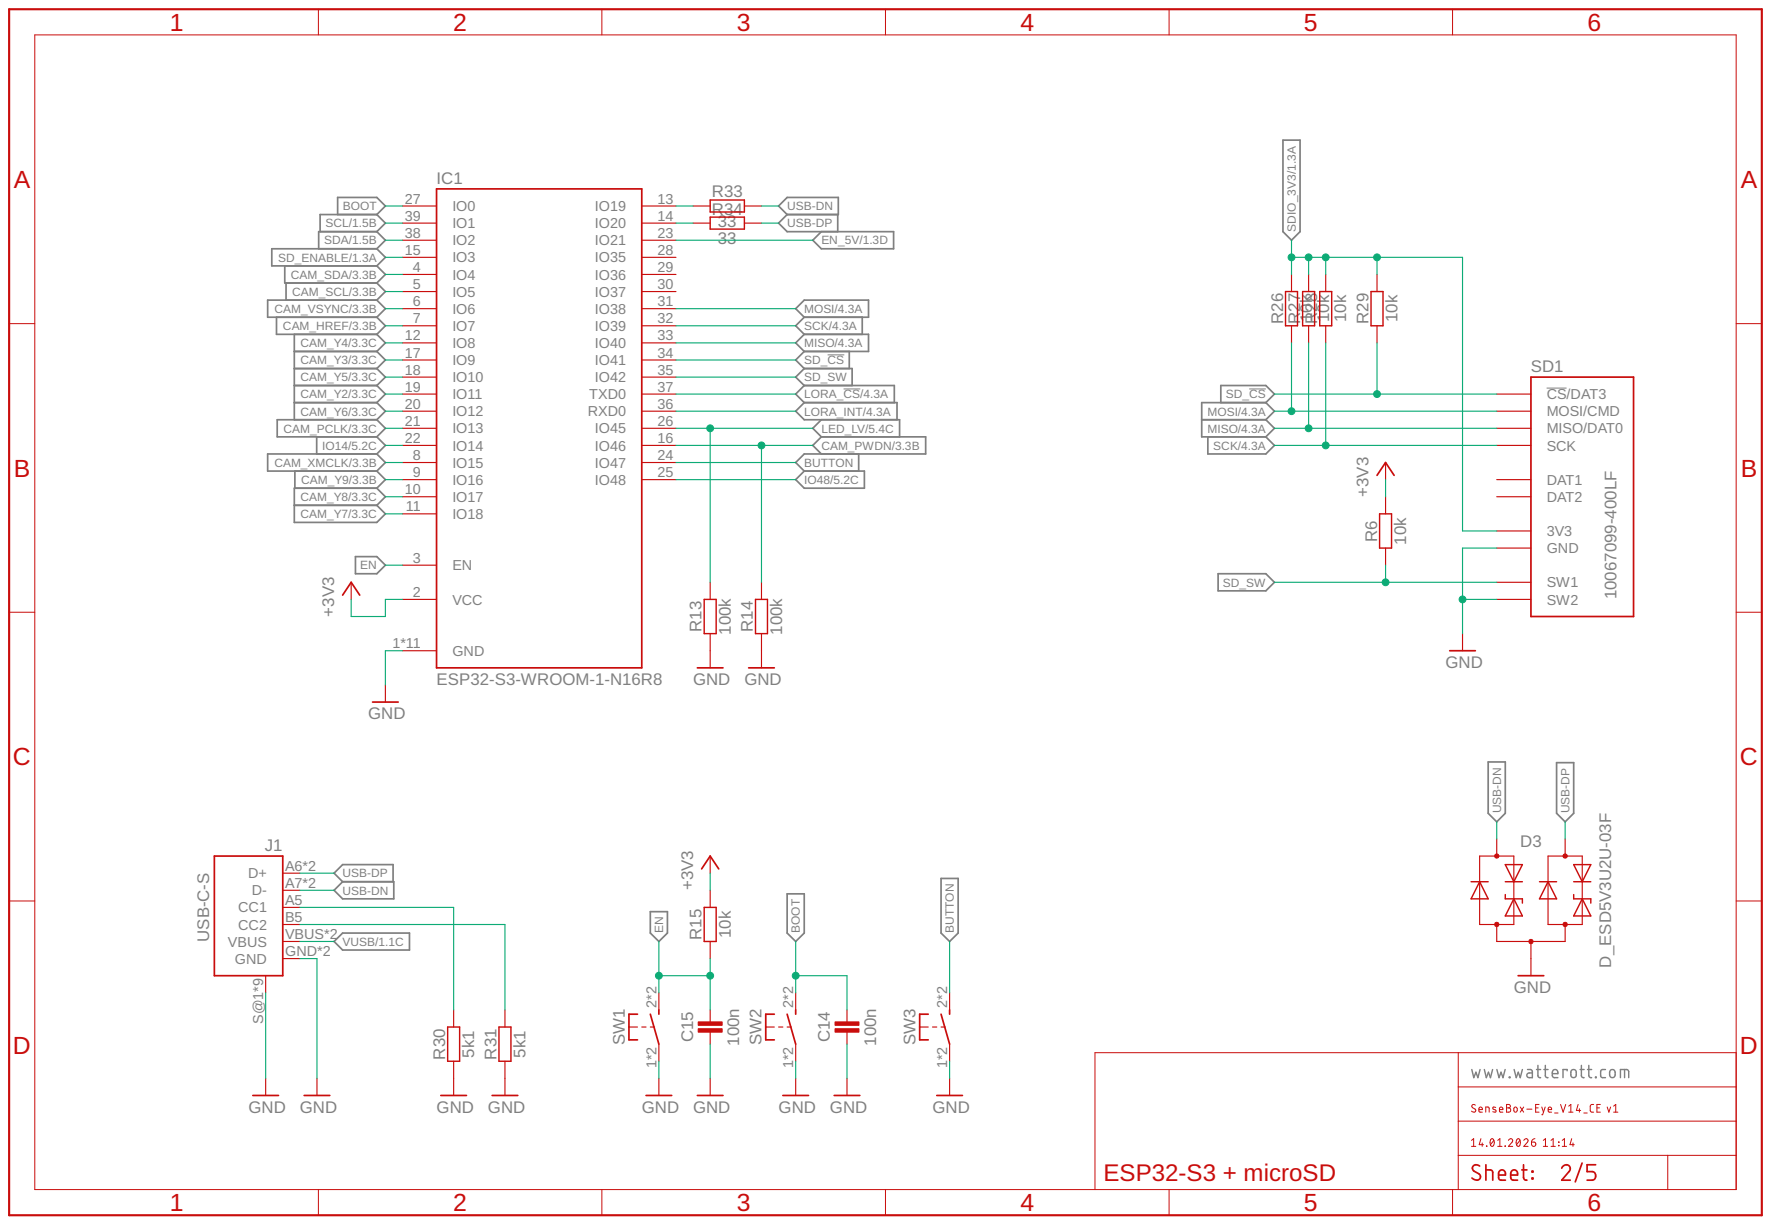
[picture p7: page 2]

10k 10k 10k 10k D_ESD5V3U2U-03F 5k1 5k1 GND GND GND GND 3333 100n 100n +3V3 GND GND GND GND GND GND GND GND 100k 100k GND GND 10k +3V3 10k +3V3 IC1 ESP32-S3-WROOM-1-N16R8 IO36 29 IO39 32 IO38 31 IO35 28 IO37 30 IO40 33 IO48 25 IO14 22 IO12 20 IO13 21 IO9 17 IO10 18 IO11 19 IO47 24 IO1 39 IO3 15 IO21 23 IO19 13 IO18 11 IO5 5 IO17 10 IO16 9 IO4 4 IO0 27 IO2 38 IO15 8 IO8 12 IO7 7 IO6 6 EN 3 VCC 2 GND 1*11 IO41 34 IO42 35 IO45 26 IO46 16 TXD0 37 RXD0 36 IO20 14 SD1 10067099-400LF DAT2 CS/DAT3 MOSI/CMD 3V3 SCK GND MISO/DAT0 DAT1 SW1 SW2 R26 R27 R28 R29 J1 USB-C-SD+ A6*2 D- A7*2 VBUS VBUS*2 GND GND*2 S@1*9 CC1 A5 CC2 B5 D3 R30 R31 R33 R34 C14 C15 SW3 1*2 2*2 SW1 1*2 2*2 SW2 1*2 2*2 R13 R14 R15 R6 CAM_SDA/3.3B CAM_SCL/3.3B CAM_HREF/3.3B CAM_Y4/3.3C CAM_Y3/3.3C CAM_Y5/3.3C CAM_Y2/3.3C CAM_Y6/3.3C CAM_PCLK/3.3C BUTTON CAM_XMCLK/3.3B BUTTON CAM_Y9/3.3B CAM_Y8/3.3C CAM_Y7/3.3C CAM_PWDN/3.3B EN_5V/1.3D SD_ENABLE/1.3A SCL/1.5B CAM_VSYNC/3.3B MOSI/4.3A MOSI/4.3A MISO/4.3A MISO/4.3A SCK/4.3A SCK/4.3A SDIO_3V3/1.3A SD_CS SD_CS USB-DP USB-DP USB-DP USB-DN USB-DN USB-DN VUSB/1.1C LORA_CS/4.3A LORA_INT/4.3A BOOT BOOTEN EN SDA/1.5B LED_LV/5.4C SD_SW SD_SW IO14/5.2C IO48/5.2C ESP32-S3 + microSD ABCD 1 2 3 4 5 6 ABCD 1 2 3 4 5 6

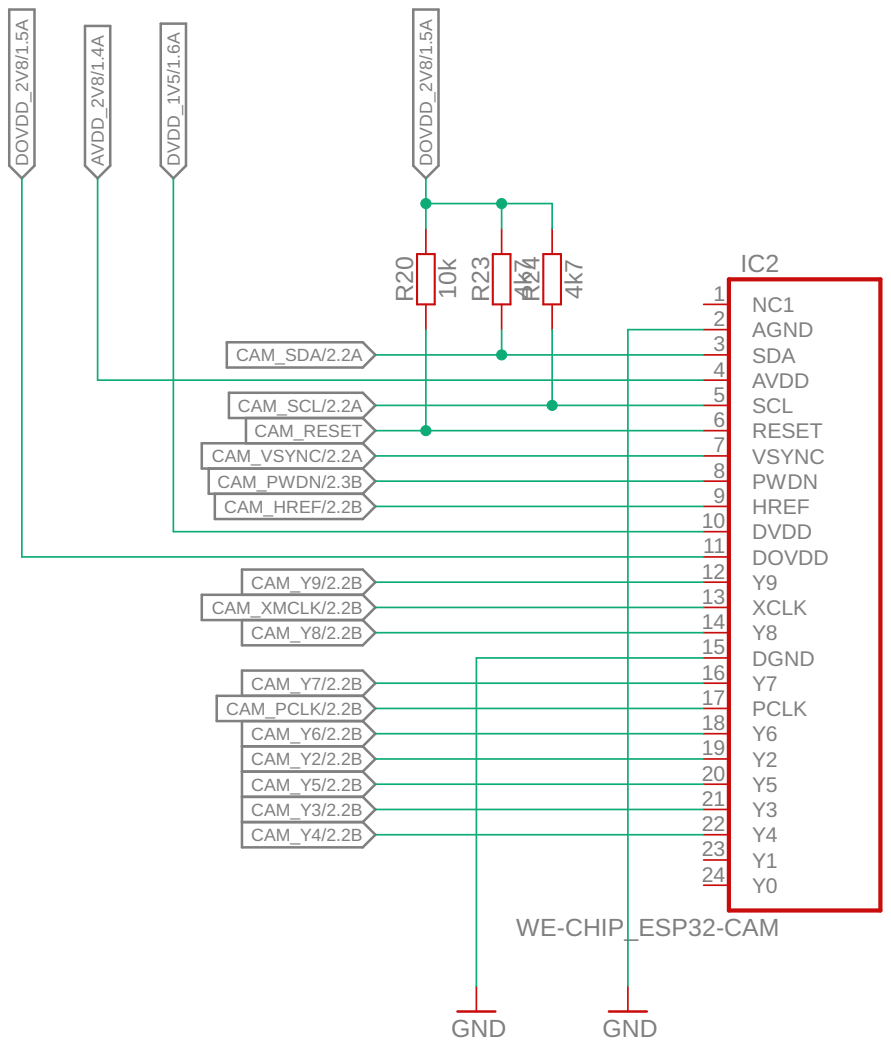
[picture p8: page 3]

10k 4k7 4k7 GND GND WE-CHIP_ESP32-CAM R20 R23 R24IC2AGND 2 AVDD 4 DGND 15 DOVDD 11 DVDD 10 HREF 9 NC1 1 PCLK 17 PWDN 8 RESET 6 SCL 5 SDA 3 VSYNC 7 XCLK 13 Y0 24 Y1 23 Y2 19 Y3 21 Y4 22 Y5 20 Y6 18 Y7 16 Y8 14 Y9 12 CAM_SDA/2.2A CAM_SCL/2.2A AVDD_2V8/1.4A CAM_RESET CAM_VSYNC/2.2A CAM_PWDN/2.3B CAM_HREF/2.2B DVDD_1V5/1.6A CAM_Y9/2.2B CAM_XMCLK/2.2B CAM_Y8/2.2B CAM_Y7/2.2B CAM_Y6/2.2B CAM_Y2/2.2B CAM_Y5/2.2B CAM_Y3/2.2B CAM_Y4/2.2B DOVDD_2V8/1.5A DOVDD_2V8/1.5A CAM_PCLK/2.2B Kamera ABCD 1 2 3 4 5 6 ABCD 1 2 3 4 5 6

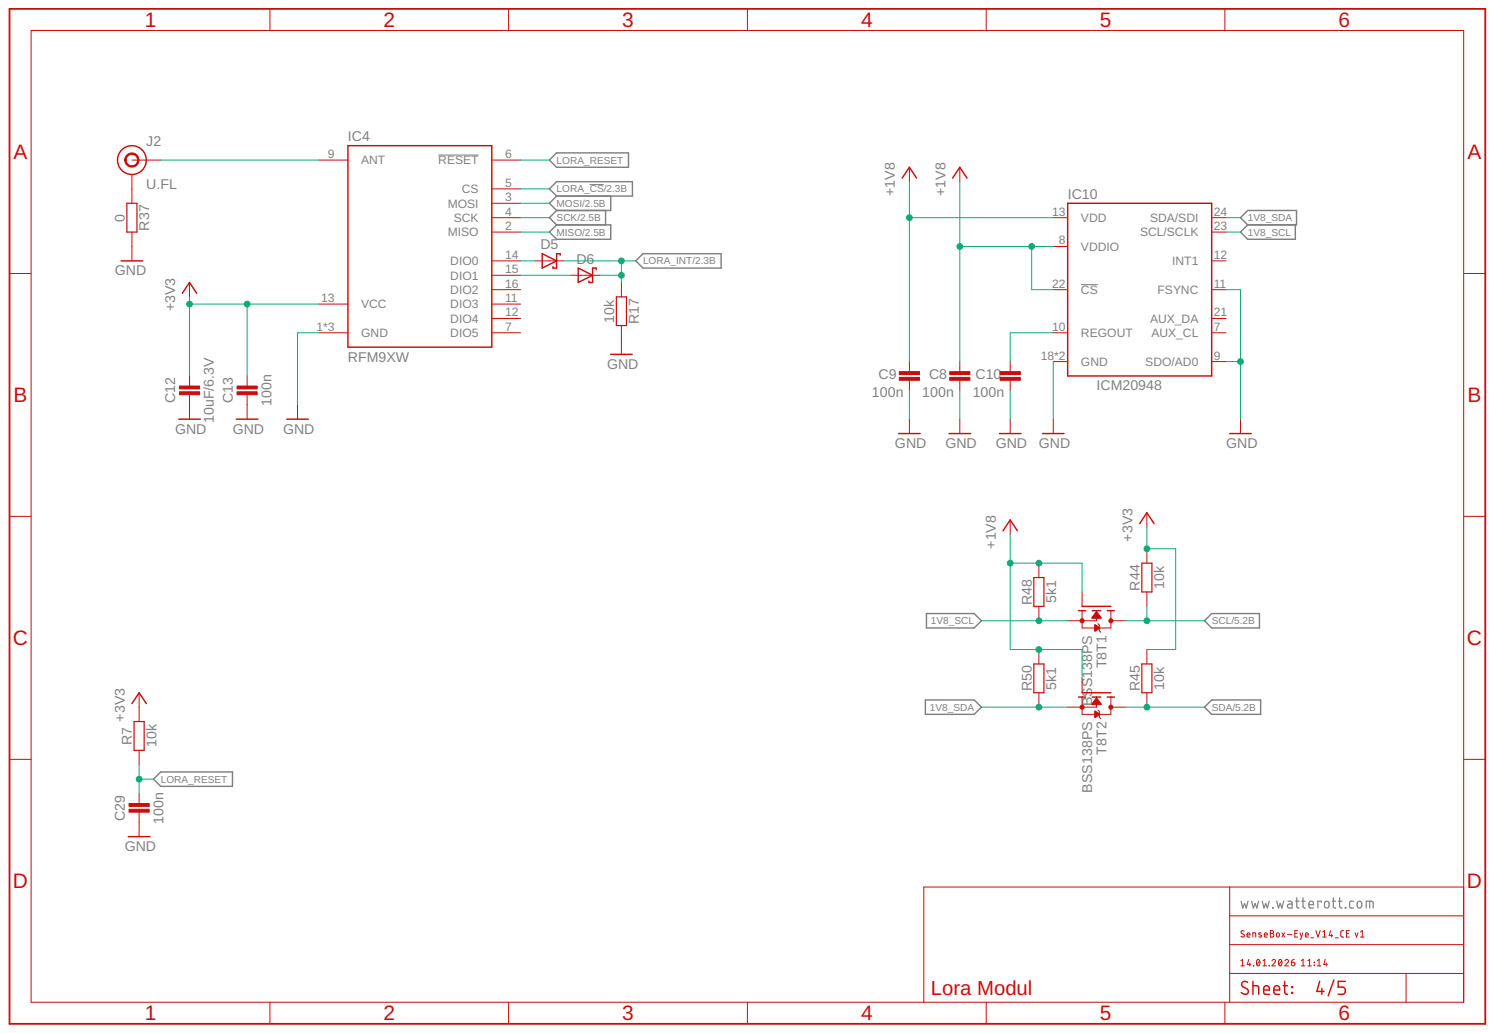
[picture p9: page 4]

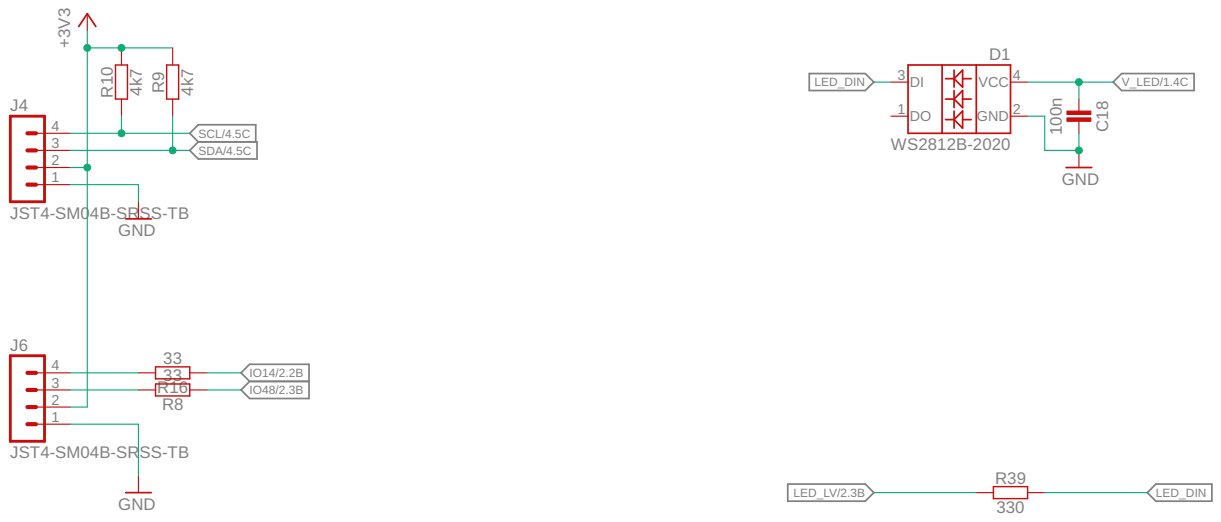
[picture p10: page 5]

33 | IO14/2.2B
R16 | IO48/2.3B

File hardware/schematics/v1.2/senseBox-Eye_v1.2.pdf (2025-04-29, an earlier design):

# VBAT VBAT

A

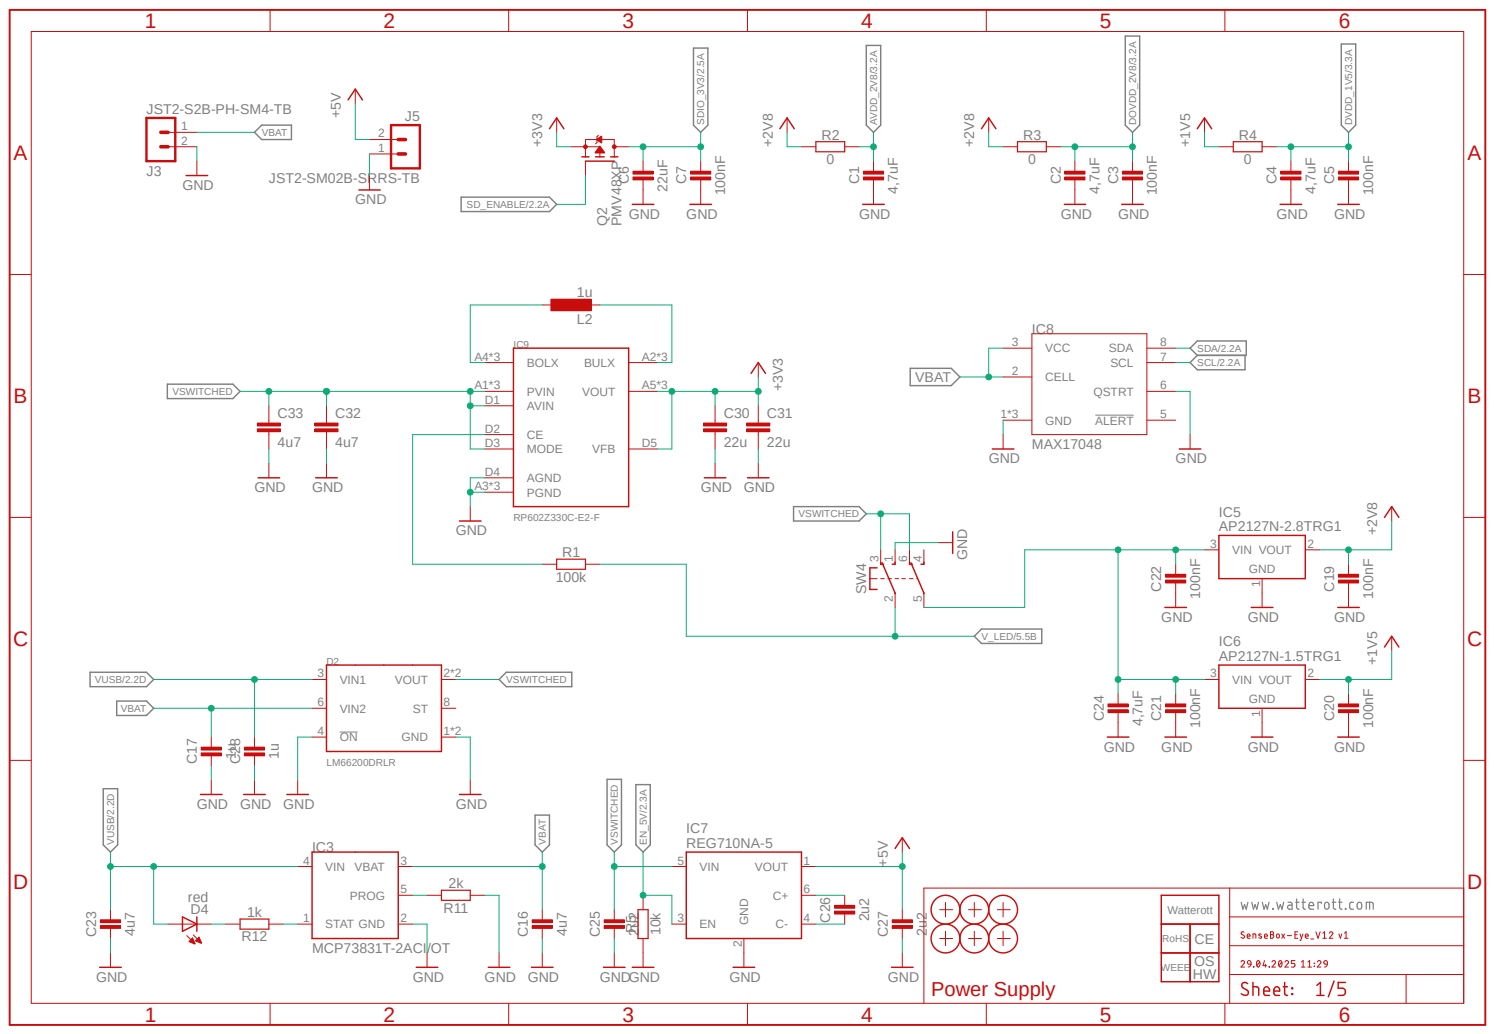
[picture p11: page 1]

ESP32-S3 + microSD ABCD | 1 | 2 | 3 | 4 | 5 | 6 | ABCD 1 | 2 | 3 | 4 | 5 | 6

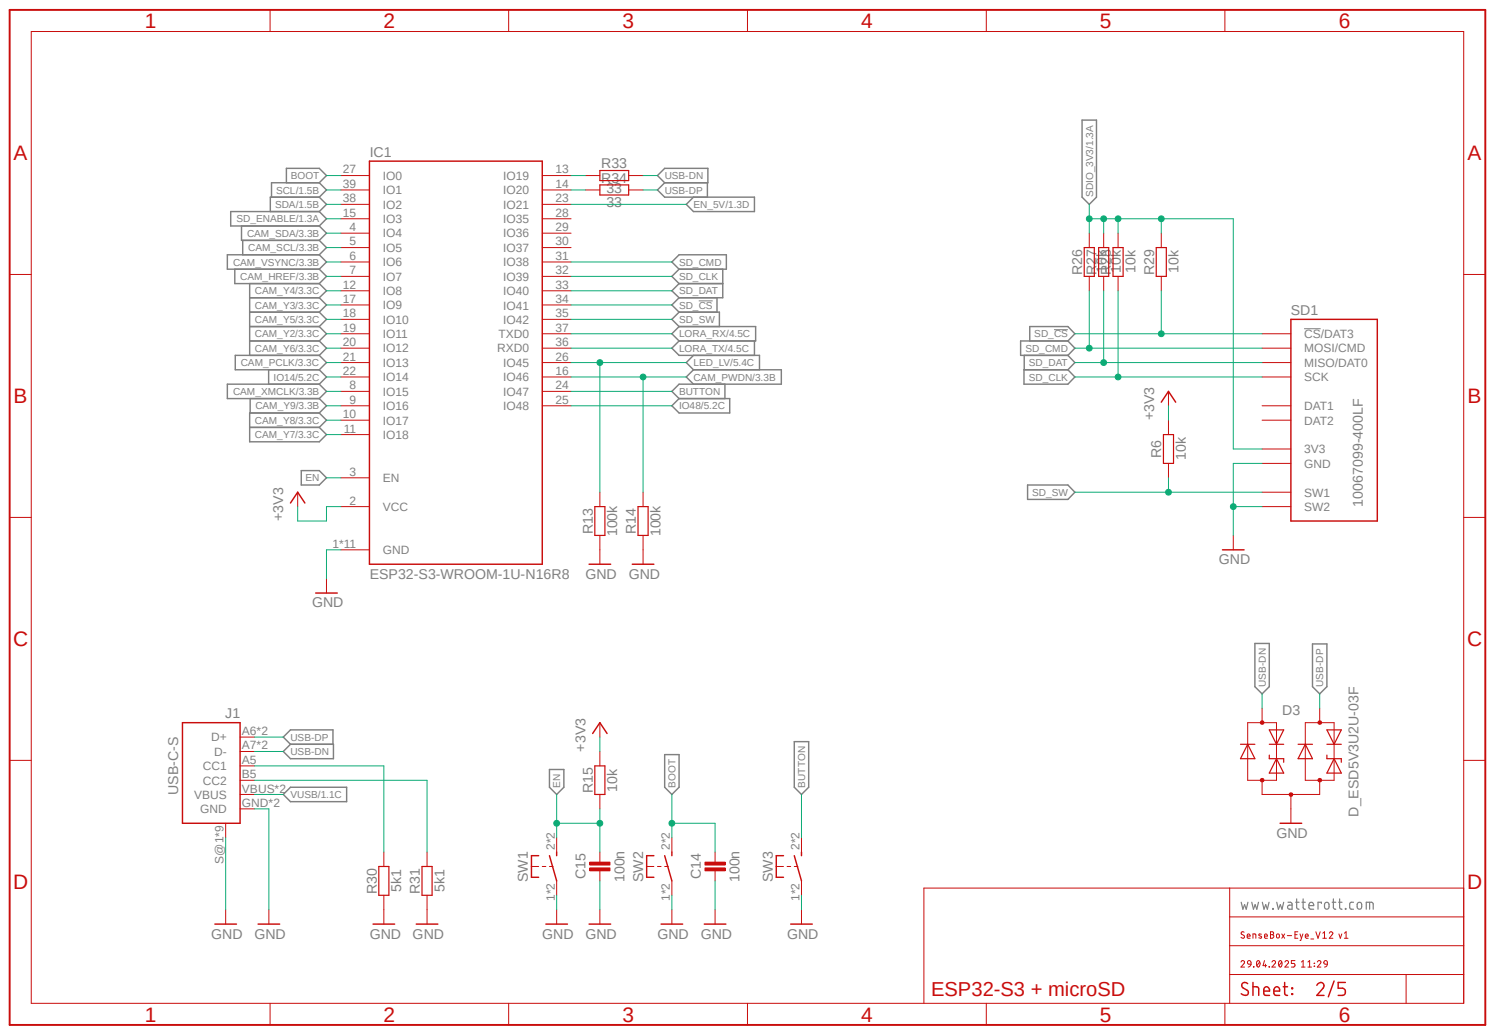
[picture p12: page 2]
10k 10k 10k 10k D_ESD5V3U2U-03F 5k1 5k1; GND; GND GND GND; GND GND; GND ¹⁰⁰k; GND GND 10k +3V³; ESP32-S3-WROOM-1U-N16R8; VCC; GND 1*11; TXD0; RXD0; 10067099⁻400LF DAT2; CS/DAT3 MOSI/CMD; SCK; MISO/DAT0; DAT1; SW2 R²⁶ R²⁷ R²⁸; R²⁹; J1 USB⁻C⁻S; VBUS; VBUS*2; GND*2 S@¹*9; D3 R³⁰; R³¹; R34 C¹⁵; C¹⁴; SW³ 1*2 2*2 SW¹ 1*2 2*2; SW² 1*2 2*2 R¹³; R¹⁴ R¹⁵; CAM_SDA/3.3B CAM_SCL/3.3B; CAM_HREF/3.3B CAM_Y4/3.3C CAM_Y3/3.3C CAM_Y5/3.3C CAM_Y2/3.3C CAM_Y6/3.3C; CAM_PCLK/3.3C; BUTTON; CAM_XMCLK/3.3B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

# CAM_HREF/2.2B DVDD_1V⁵/1.6A

Kamera ABCD | 1 | 2 | 3 | 4 | 5 | 6 | ABCD 1 | 2 | 3 | 4 | 5 | 6

GND; WE-CHIP_ESP32-CAM R²⁰; R²³; R²⁴; AGND; AVDD; DGND 15; DOVDD 11; DVDD 10; HREF 9; PCLK 17; PWDN; RESET; SCL; SDA; VSYNC; XCLK 13; CAM_SDA/2.2A; CAM_SCL/2.2A AVDD_2V⁸/1.4A; CAM_RESET CAM_VSYNC/2.2A CAM_PWDN/2.3B; CAM_Y9/2.2B CAM_XMCLK/2.2B CAM_Y8/2.2B; CAM_Y7/2.2B; CAM_Y6/2.2B CAM_Y2/2.2B CAM_Y5/2.2B CAM_Y3/2.2B; CAM_Y4/2.2B DOVDD_2V⁸/1.5A; DOVDD_2V⁸/1.5A; CAM_PCLK/2.2B

A

A

LBAA0QB1SJ-686; U.FL MLZ2012N¹⁵⁰LT000 +3V³; 010k BLM15AG102SN1D; GND; GND 100n; GND¹⁰k +3V³; GND 1*23; VDD_MCU 7; MCU_RST; ANT; MCU_BOOT0; C¹⁰; C¹¹; C¹²; C¹³; R³⁸; R³⁷ L3 C²⁹ R⁷; LORA_TX/2.3B LORA_RX/2.3B; LORA_RESET; LORA-USB-DN; Lora Modul

VDD_RF 5
VDD_USB 35

DCDC_SW 3

VREG 2

LORA-USB-DP

A

A

JST4-SM04B-SRSS-TB; GND⁴k7; GND; C¹⁸J4; R¹⁰; LED_DIN; V_LED/1.4C; SDA/2.2A; SCL/2.2A; LED_LV/2.3B; IOs + LED

DO | VCC GND

33 | IO14/2.2B
R16 | IO48/2.3B

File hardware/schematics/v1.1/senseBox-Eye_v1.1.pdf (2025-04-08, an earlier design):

# VBAT VBAT

A


R34 C¹⁵ | C¹⁴ | SW³ 1*2 2*2 SW¹ 1*2 2*2 | SW² 1*2 2*2 R¹³ | R¹⁴ R¹⁵

A

10k 10k 10k 10k D_ESD5V3U2U-03F 5k1 5k1; GND; GND GND GND; GND GND; GND ¹⁰k; GND GND 10k +3V³; ESP32-S3-WROOM-1U-N16R8; VCC 2; GND 1*11; TXD0; RXD0; 10067099⁻400LF DAT2; CS/DAT3 MOSI/CMD; SCK; MISO/DAT0; DAT1; SW2 R²⁶ R²⁷ R²⁸; R²⁹; J1 USB⁻C⁻S; VBUS; VBUS*2; GND*2 S@¹*9; D3 R³⁰; R³¹; IO3/5.2C CAM_SDA/3.3B CAM_SCL/3.3B; CAM_HREF/3.3B CAM_Y4/3.3C CAM_Y3/3.3C CAM_Y5/3.3C CAM_Y2/3.3C CAM_Y6/3.3C; CAM_PCLK/3.3C; BUTTON; CAM_XMCLK/3.3B; CAM_Y9/3.3B CAM_Y8/3.3C CAM_Y7/3.3C; SD_ENABLE/1.3A; SCL/1.5B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

# CAM_HREF/2.2B DVDD_1V⁵/1.6A

Kamera ABCD | 1 | 2 | 3 | 4 | 5 | 6 | ABCD 1 | 2 | 3 | 4 | 5 | 6

GNDGND; GND R¹⁹ R²⁰; WE-CHIP_ESP32-CAM R²³; R²⁴; AGND; AVDD; DGND 15; DOVDD 11; DVDD 10; HREF 9; PCLK 17; PWDN; RESET; SCL; SDA; VSYNC; XCLK 13; CAM_SDA/2.2A; CAM_SCL/2.2A AVDD_2V⁸/1.4A; CAM_RESET CAM_VSYNC/2.2A CAM_PWDN; CAM_Y9/2.2B CAM_XMCLK/2.2B CAM_Y8/2.2B; CAM_Y7/2.2B; CAM_Y6/2.2B CAM_Y2/2.2B CAM_Y5/2.2B CAM_Y3/2.2B; CAM_Y4/2.2B DOVDD_2V⁸/1.5A; DOVDD_2V⁸/1.5A; CAM_PCLK/2.2B

A

A

LBAA0QB1SJ-686; U.FL MLZ2012N¹⁵⁰LT000 +3V³; 010k BLM15AG102SN1D; GND; GND 100n; GND¹⁰k +3V³; GND 1*23; VDD_MCU 7; MCU_RST; ANT; MCU_BOOT0; C¹⁰; C¹¹; C¹²; C¹³; R³⁸; R³⁷ L3 C²⁹ R⁷; LORA_TX/2.3B LORA_RX/2.3B; LORA_RESET; LORA-USB-DN; Lora Modul

VDD_RF 5
VDD_USB 35

DCDC_SW 3

VREG 2

LORA-USB-DP

A

A

JST4-SM04B-SRSS-TB; GND⁴k7; GND; C¹⁸J4; R¹⁰; LED_DIN; V_LED/1.4C; SDA/2.2A; SCL/2.2A; LED_LV/2.2B; IOs + LED

DO | VCC GND






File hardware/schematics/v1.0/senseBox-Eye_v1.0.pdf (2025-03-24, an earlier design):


red D4 1k | 2k

WEEE Watterott RoHS

Power Supply

25.02.25 12:50 /Users/mariopesch/Downloads/SenseBox-Eye.sch (Sheet: 1/5)


25.02.25 12:50 /Users/mariopesch/Downloads/SenseBox-Eye.sch (Sheet: 2/5)


25.02.25 12:50 /Users/mariopesch/Downloads/SenseBox-Eye.sch (Sheet: 3/5)


25.02.25 12:50 /Users/mariopesch/Downloads/SenseBox-Eye.sch (Sheet: 4/5)


25.02.25 12:50 /Users/mariopesch/Downloads/SenseBox-Eye.sch (Sheet: 5/5)

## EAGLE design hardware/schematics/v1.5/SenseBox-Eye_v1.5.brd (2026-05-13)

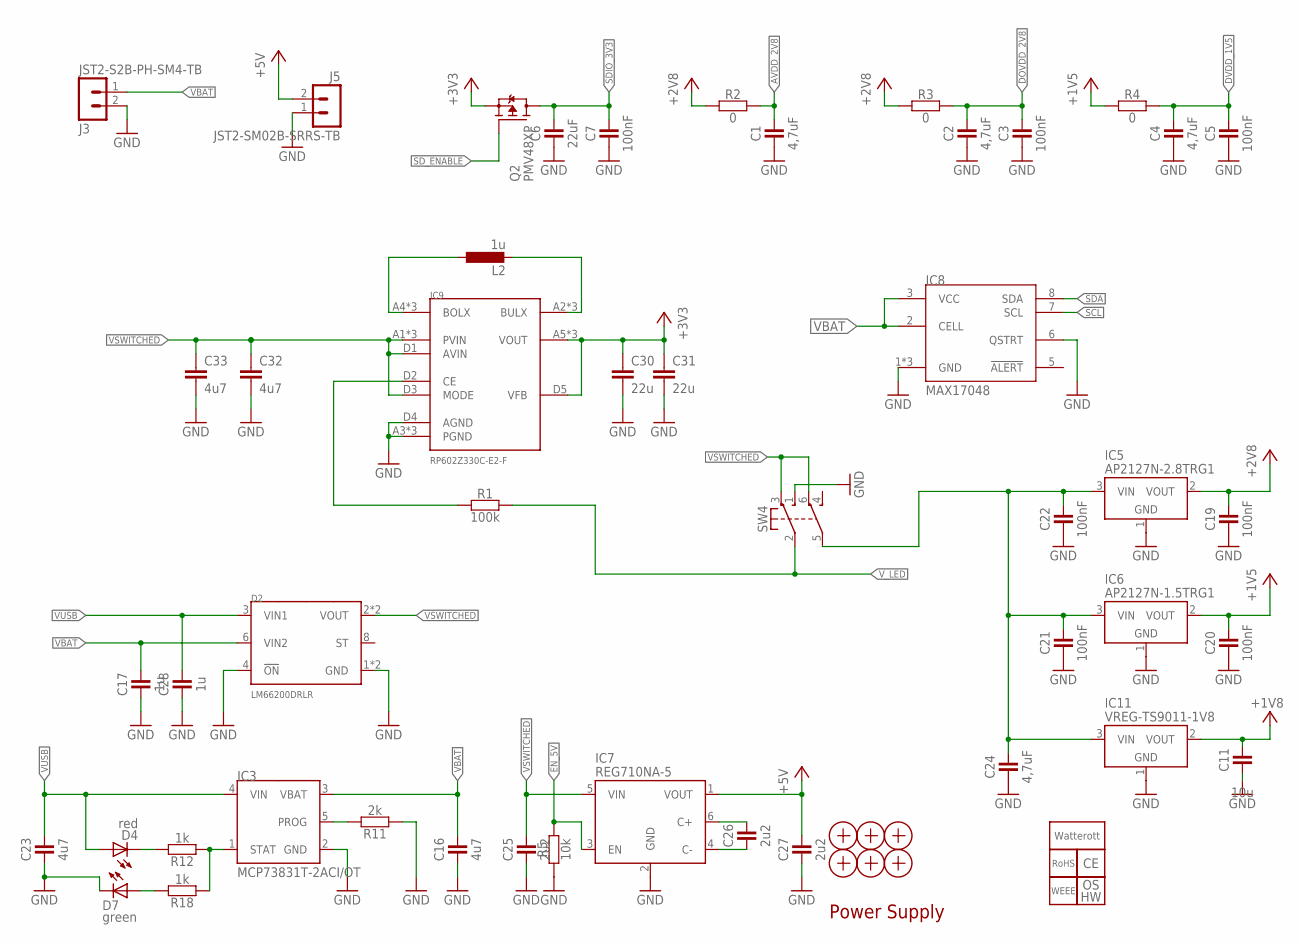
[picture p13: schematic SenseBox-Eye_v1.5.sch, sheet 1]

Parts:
C1, C2, C4, C24: 4,7uF; C0402
C3, C5, C7, C19, C20, C21, C22: 100nF; C0402
C6: 22uF; C0402
C11: 10u; C0402
C16, C23: 4u7; C0402
C17, C28: 1u; C0402
C25, C26, C27: 2u2; C0402
C30, C31: 22u; 0805N
C32, C33: 4u7; 0603N
D2: LM66200DRLR; SOT-5X3
D4: red; 0603N
D7: green; 0603N
IC3: MCP73831T-2ACI/OT; SOT23-5
IC5: AP2127N-2.8TRG1; SOT23
IC6: AP2127N-1.5TRG1; SOT23
IC7: REG710NA-5; SOT23-6
IC8: MAX17048; UDFN8_2020
IC9: RP602Z330C-E2-F; WLCSP-20-P1
IC11: VREG-TS9011-1V8; SOT23
J3: JST2-S2B-PH-SM4-TB; JST_S2B-PH-SM4-TB
J5: JST2-SM02B-SRRS-TB; JST_SM02B-SRSS-TB
L2: 1u; 5040
LOGO2: LOGO_CE-5; CE_5MM
LOGO3: LOGO_OSHW-2; OSHW_2MM
LOGO4: LOGO_ROHS-2; ROHS_2MM
LOGO5: LOGO_WEEE-4; WEEE_4MM
LOGO6: LOGO_SPARK-2; SPARK_2MM
Q2: PMV48XP; SOT23
R1: 100k; C0402
R2, R3, R4: 0; C0402
R5: 10k; C0402
R11: 2k; C0402
R12, R18: 1k; C0402
SW4: SW-2UM-CUS22B; CUS22B
X1, X2, X3, X4, X5, X6: PASSER-04; PASSER_04MM

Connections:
+1V5: C20.2, IC6.2 (VOUT), R4.1
+1V8: C11.2, IC11.2 (VOUT); also elsewhere on the board
+2V8: C19.2, IC5.2 (VOUT), R2.1, R3.1
+3V3: C30.1, C31.1, IC9.A5 (VOUT), IC9.B5 (VOUT), IC9.C5 (VOUT), IC9.D5 (VFB), Q2.2 (S); also elsewhere on the board
+5V: C27.2, IC7.1 (VOUT), J5.2
AVDD_2V8: C1.2, R2.2; also elsewhere on the board
BOLX: IC9.A4 (BOLX), IC9.B4 (BOLX), IC9.C4 (BOLX), L2.1
BULX: IC9.A2 (BULX), IC9.B2 (BULX), IC9.C2 (BULX), L2.2
DOVDD_2V8: C2.2, C3.2, R3.2; also elsewhere on the board
DVDD_1V5: C4.2, C5.2, R4.2; also elsewhere on the board
ENABLE_3V3: IC9.D2 (CE), R1.1
EN_5V: IC7.3 (EN), R5.2; also elsewhere on the board
GND: C1.1, C2.1, C3.1, C4.1, C5.1, C6.1, C7.1, C11.1, C16.1, C17.1, C19.1, C20.1, C21.1, C22.1, C23.1, C24.1, C25.1, C27.1, C28.1, C30.2, C31.2, C32.2, C33.2, D2.1 (GND), D2.4 (!ON), D2.5 (GND), D7.C, IC3.2 (GND), IC5.1 (GND), IC6.1 (GND), IC7.2 (GND), IC8.1 (GND), IC8.4 (GND), IC8.6 (QSTRT), IC8.TP (GND), IC9.A3 (PGND), IC9.B3 (PGND), IC9.C3 (PGND), IC9.D4 (AGND), IC11.1 (GND), J3.2, J5.1, R5.1, R11.1, SW4.1 (NO1); also elsewhere on the board
unnamed: C26.2, IC7.6 (C+)
unnamed: C26.1, IC7.4 (C-)
unnamed: D7.A, R18.2
unnamed: D4.C, R12.2
unnamed: IC3.1 (STAT), R12.1, R18.1
unnamed: IC3.5 (PROG), R11.2
SCL: IC8.7 (SCL); also elsewhere on the board
SDA: IC8.8 (SDA); also elsewhere on the board
SDIO_3V3: C6.2, C7.2, Q2.3 (D); also elsewhere on the board
SD_ENABLE: Q2.1 (G); also elsewhere on the board
VBAT: C16.2, C17.2, D2.6 (VIN2), IC3.3 (VBAT), IC8.2 (CELL), IC8.3 (VCC), J3.1
VIN: C21.2, C22.2, C24.2, IC5.3 (VIN), IC6.3 (VIN), IC11.3 (VIN), SW4.5 (C2)
VSWITCHED: C25.2, C32.1, C33.1, D2.2 (VOUT), D2.7 (VOUT), IC7.5 (VIN), IC9.A1 (PVIN), IC9.B1 (PVIN), IC9.C1 (PVIN), IC9.D1 (AVIN), IC9.D3 (MODE), SW4.3 (NC1), SW4.6 (NC2)
VUSB: C23.2, C28.2, D2.3 (VIN1), D4.A, IC3.4 (VIN); also elsewhere on the board
V_LED: R1.2, SW4.2 (C1); also elsewhere on the board

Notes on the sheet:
Power Supply

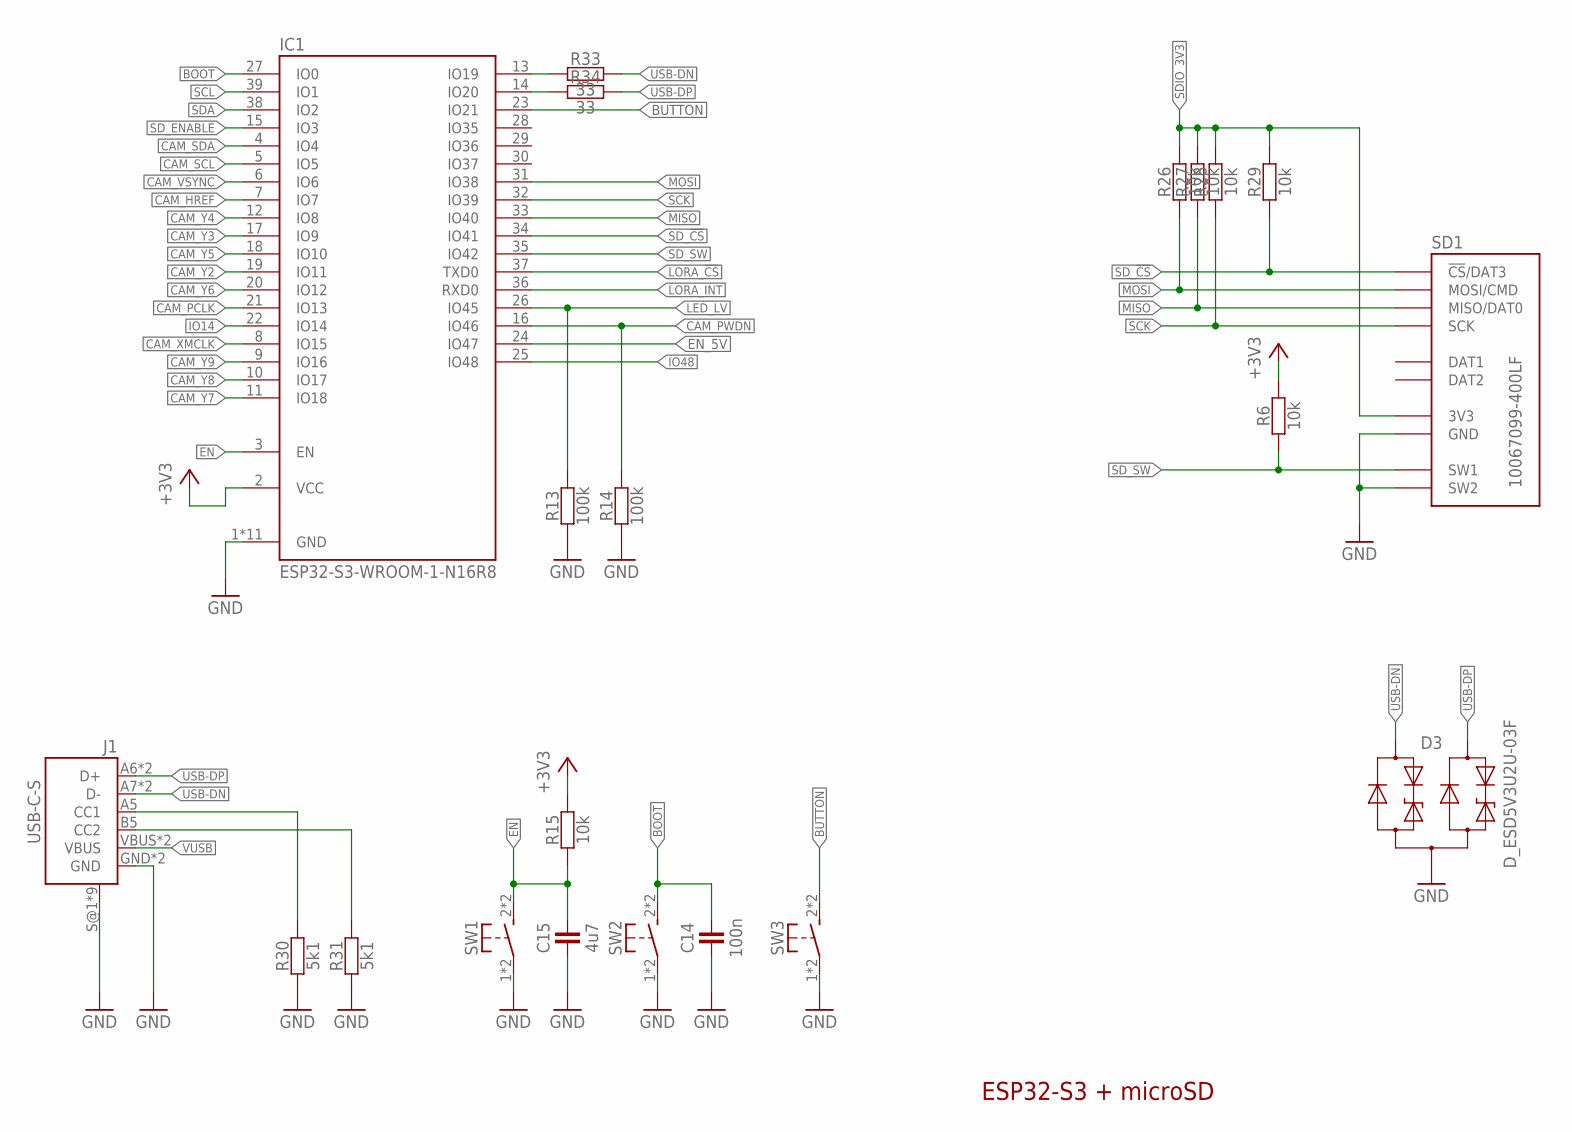
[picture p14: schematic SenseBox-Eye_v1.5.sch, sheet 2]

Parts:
C14: 100n; C0402
C15: 4u7; C0402
D3: D_ESD5V3U2U-03F; SOT723
IC1: ESP32-S3-WROOM-1-N16R8; ESP32-S3-WROOM-1
J1: USB-C-S
R6, R15, R26, R27, R28, R29: 10k; C0402
R13, R14: 100k; C0402
R30, R31: 5k1; C0402
R33, R34: 33; C0402
SD1: 10067099-400LF; SD_47309XXXX
SW1, SW2, SW3: SW-TACTILE-TL3305; TL3305

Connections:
+3V3: IC1.2 (VCC), R6.2, R15.2; also elsewhere on the board
BOOT: C14.2, IC1.27 (IO0), SW2.2 (S1), SW2.3 (S1)
BUTTON: IC1.23 (IO21), SW3.2 (S1), SW3.3 (S1)
CAM_HREF: IC1.7 (IO7); also elsewhere on the board
CAM_PCLK: IC1.21 (IO13); also elsewhere on the board
CAM_PWDN: IC1.16 (IO46), R14.2; also elsewhere on the board
CAM_SCL: IC1.5 (IO5); also elsewhere on the board
CAM_SDA: IC1.4 (IO4); also elsewhere on the board
CAM_VSYNC: IC1.6 (IO6); also elsewhere on the board
CAM_XMCLK: IC1.8 (IO15); also elsewhere on the board
CAM_Y2: IC1.19 (IO11); also elsewhere on the board
CAM_Y3: IC1.17 (IO9); also elsewhere on the board
CAM_Y4: IC1.12 (IO8); also elsewhere on the board
CAM_Y5: IC1.18 (IO10); also elsewhere on the board
CAM_Y6: IC1.20 (IO12); also elsewhere on the board
CAM_Y7: IC1.11 (IO18); also elsewhere on the board
CAM_Y8: IC1.10 (IO17); also elsewhere on the board
CAM_Y9: IC1.9 (IO16); also elsewhere on the board
CC1: J1.A5 (CC1), R30.2
CC2: J1.B5 (CC2), R31.2
EN: C15.2, IC1.3 (EN), R15.1, SW1.2 (S1), SW1.3 (S1)
EN_5V: IC1.24 (IO47); also elsewhere on the board
GND: C14.1, C15.1, D3.3 (A), IC1.1 (GND), IC1.40 (GND), IC1.P$1 (GND), IC1.P$2 (GND), IC1.P$3 (GND), IC1.P$4 (GND), IC1.P$5 (GND), IC1.P$6 (GND), IC1.P$7 (GND), IC1.P$8 (GND), IC1.P$9 (GND), J1.GND, J1.GND2 (GND), J1.S@1 (SHIELD), J1.S@2 (SHIELD), J1.S@3 (SHIELD), J1.S@4 (SHIELD), J1.S@5 (SHIELD), J1.S@6 (SHIELD), J1.S@7 (SHIELD), J1.S@8 (SHIELD), J1.S@9 (SHIELD), R13.1, R14.1, R30.1, R31.1, SD1.GND, SD1.GND@1 (GND), SD1.GND@2 (GND), SD1.SW2, SW1.1, SW1.4 (P1), SW2.1, SW2.4 (P1), SW3.1, SW3.4 (P1); also elsewhere on the board
IO14: IC1.22 (IO14); also elsewhere on the board
IO19: IC1.13 (IO19), R33.1
IO20: IC1.14 (IO20), R34.1
IO48: IC1.25 (IO48); also elsewhere on the board
LED_LV: IC1.26 (IO45), R13.2; also elsewhere on the board
LORA_!CS: IC1.37 (TXD0); also elsewhere on the board
LORA_INT: IC1.36 (RXD0); also elsewhere on the board
MISO: IC1.33 (IO40), R27.1, SD1.MISO (MISO/DAT0); also elsewhere on the board
MOSI: IC1.31 (IO38), R26.1, SD1.MOSI (MOSI/CMD); also elsewhere on the board
SCK: IC1.32 (IO39), R28.1, SD1.SCK; also elsewhere on the board
SCL: IC1.39 (IO1); also elsewhere on the board
SDA: IC1.38 (IO2); also elsewhere on the board
SDIO_3V3: R26.2, R27.2, R28.2, R29.2, SD1.VCC (3V3); also elsewhere on the board
SD_!CS: IC1.34 (IO41), R29.1, SD1.CS (!CS!/DAT3)
SD_ENABLE: IC1.15 (IO3); also elsewhere on the board
SD_SW: IC1.35 (IO42), R6.1, SD1.SW1
USB-DN: D3.1 (C1), J1.A7 (D-), J1.B7 (D-), R33.2
USB-DP: D3.2 (C2), J1.A6 (D+), J1.B6 (D+), R34.2
VUSB: J1.VBUS, J1.VBUS2 (VBUS); also elsewhere on the board

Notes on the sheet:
ESP32-S3 + microSD

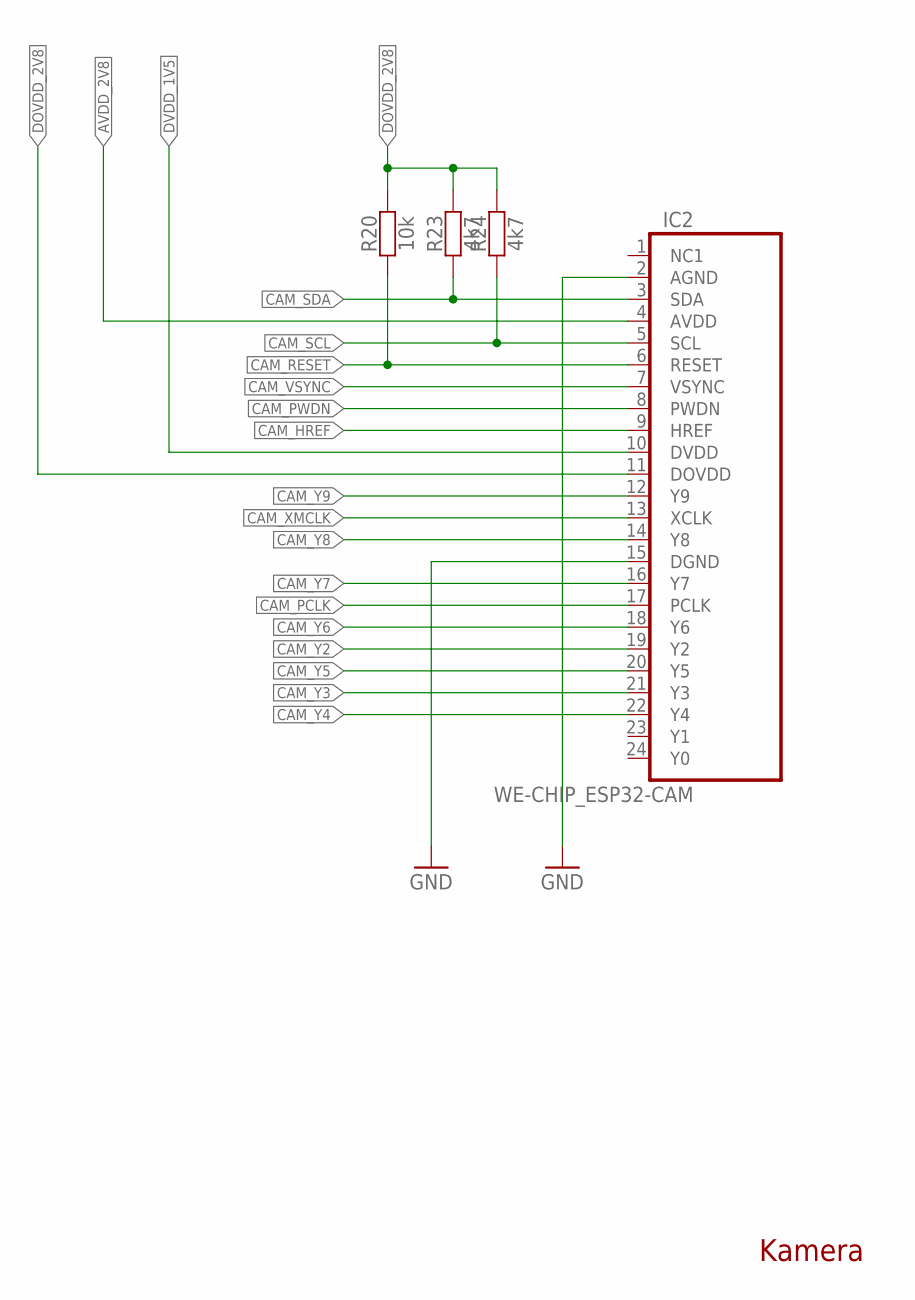
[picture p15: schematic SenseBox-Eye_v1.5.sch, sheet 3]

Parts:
IC2: WE-CHIP_ESP32-CAM; WE-CHIP_FPC24-0.5-CAM
R20: 10k; C0402
R23, R24: 4k7; C0402

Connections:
AVDD_2V8: IC2.4 (AVDD); also elsewhere on the board
CAM_HREF: IC2.9 (HREF); also elsewhere on the board
CAM_PCLK: IC2.17 (PCLK); also elsewhere on the board
CAM_PWDN: IC2.8 (PWDN); also elsewhere on the board
CAM_RESET: IC2.6 (RESET), R20.1
CAM_SCL: IC2.5 (SCL), R24.1; also elsewhere on the board
CAM_SDA: IC2.3 (SDA), R23.1; also elsewhere on the board
CAM_VSYNC: IC2.7 (VSYNC); also elsewhere on the board
CAM_XMCLK: IC2.13 (XCLK); also elsewhere on the board
CAM_Y2: IC2.19 (Y2); also elsewhere on the board
CAM_Y3: IC2.21 (Y3); also elsewhere on the board
CAM_Y4: IC2.22 (Y4); also elsewhere on the board
CAM_Y5: IC2.20 (Y5); also elsewhere on the board
CAM_Y6: IC2.18 (Y6); also elsewhere on the board
CAM_Y7: IC2.16 (Y7); also elsewhere on the board
CAM_Y8: IC2.14 (Y8); also elsewhere on the board
CAM_Y9: IC2.12 (Y9); also elsewhere on the board
DOVDD_2V8: IC2.11 (DOVDD), R20.2, R23.2, R24.2; also elsewhere on the board
DVDD_1V5: IC2.10 (DVDD); also elsewhere on the board
GND: IC2.2 (AGND), IC2.15 (DGND); also elsewhere on the board

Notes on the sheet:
Kamera

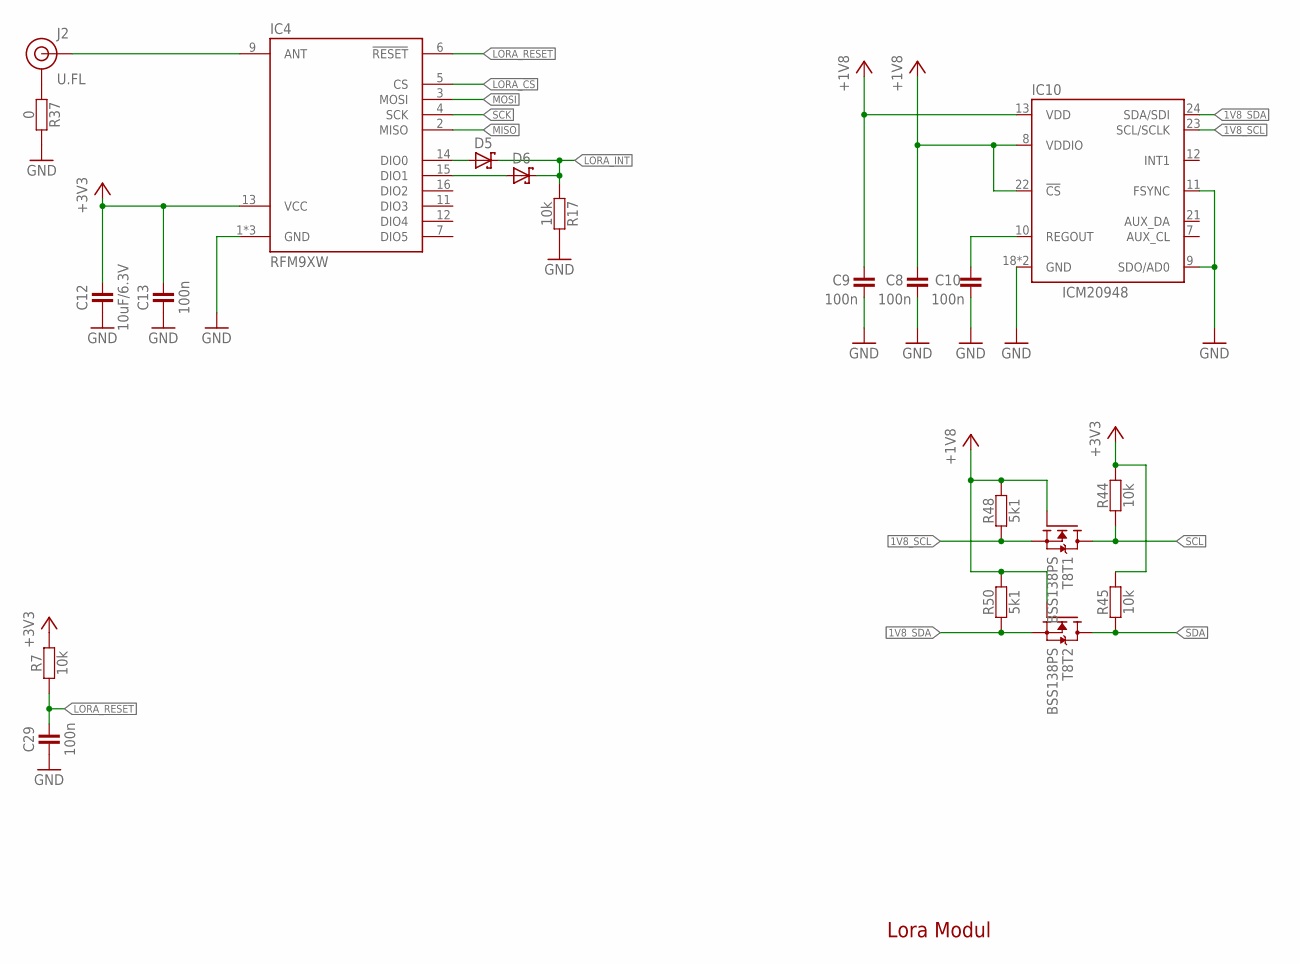
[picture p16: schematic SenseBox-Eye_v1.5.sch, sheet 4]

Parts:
C8, C9, C10, C13, C29: 100n; C0402
C12: 10uF/6.3V; C0402
D5, D6: D_SCHOTTKY-SOD523; SOD523
IC4: RFM9XW; RFM9X
IC10: ICM20948; QFN24-3X3
J2: U.FL
R7, R17, R44, R45: 10k; C0402
R37: 0; C0402
R48, R50: 5k1; C0402
T8: BSS138PS; SOT363

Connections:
1V8_SCL: IC10.23 (SCL/SCLK), R48.1, T8.1 (S)
1V8_SDA: IC10.24 (SDA/SDI), R50.1, T8.4 (S)
+1V8: C8.2, C9.2, IC10.8 (VDDIO), IC10.13 (VDD), IC10.22 (!CS), R48.2, R50.2, T8.2 (G), T8.5 (G); also elsewhere on the board
+3V3: C12.2, C13.2, IC4.13 (VCC), R7.2, R44.2, R45.2; also elsewhere on the board
ANT: IC4.9 (ANT), J2.FEED (SIGNAL)
GND: C8.1, C9.1, C10.1, C12.1, C13.1, C29.1, IC4.1 (GND), IC4.8 (GND), IC4.10 (GND), IC10.9 (SDO/AD0), IC10.11 (FSYNC), IC10.18 (GND), IC10.20 (GND), R17.1, R37.1; also elsewhere on the board
LORA_!CS: IC4.5 (CS); also elsewhere on the board
LORA_INT: D5.C, D6.C, R17.2; also elsewhere on the board
LORA_RESET: C29.2, IC4.6 (!RESET), R7.1
MISO: IC4.2 (MISO); also elsewhere on the board
MOSI: IC4.3 (MOSI); also elsewhere on the board
unnamed: D5.A, IC4.14 (DIO0)
unnamed: D6.A, IC4.15 (DIO1)
unnamed: J2.1 (GND), J2.2 (GND), R37.2
REGOUT1: C10.2, IC10.10 (REGOUT)
SCK: IC4.4 (SCK); also elsewhere on the board
SCL: R44.1, T8.6 (D); also elsewhere on the board
SDA: R45.1, T8.3 (D); also elsewhere on the board

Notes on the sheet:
Lora Modul

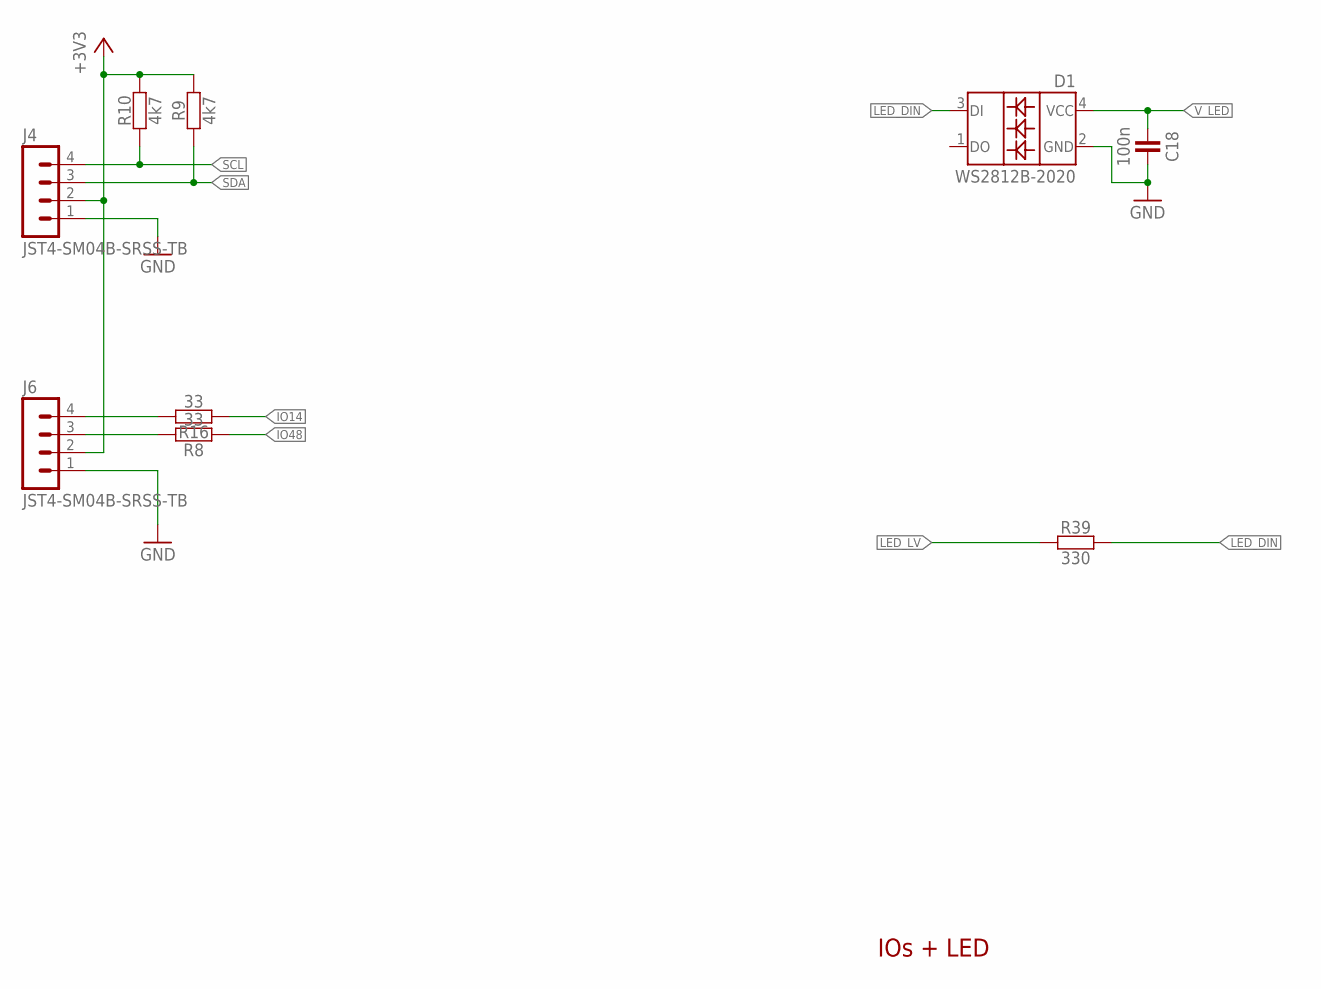
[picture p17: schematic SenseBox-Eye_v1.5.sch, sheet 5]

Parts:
C18: 100n; C0402
D1: WS2812B-2020; WS2812_2020
J4, J6: JST4-SM04B-SRSS-TB; JST_SM04B-SRSS-TB
R8, R16: 33; C0402
R9, R10: 4k7; C0402
R39: 330; C0402

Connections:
+3V3: J4.2, J6.2, R9.1, R10.1; also elsewhere on the board
GND: C18.1, D1.2 (GND), J4.1, J6.1; also elsewhere on the board
IO14: R16.2; also elsewhere on the board
IO48: R8.2; also elsewhere on the board
LED_DIN: D1.3 (DI), R39.2
LED_LV: R39.1; also elsewhere on the board
unnamed: J6.4, R16.1
unnamed: J6.3, R8.1
SCL: J4.4, R10.2; also elsewhere on the board
SDA: J4.3, R9.2; also elsewhere on the board
V_LED: C18.2, D1.4 (VCC); also elsewhere on the board

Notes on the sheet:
IOs + LED

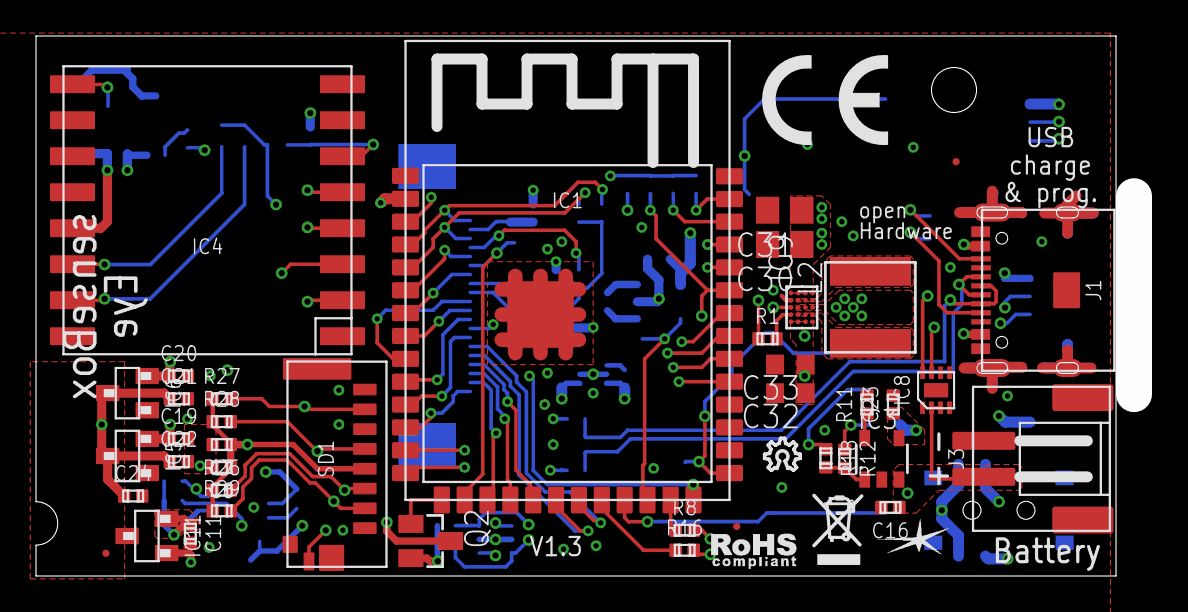
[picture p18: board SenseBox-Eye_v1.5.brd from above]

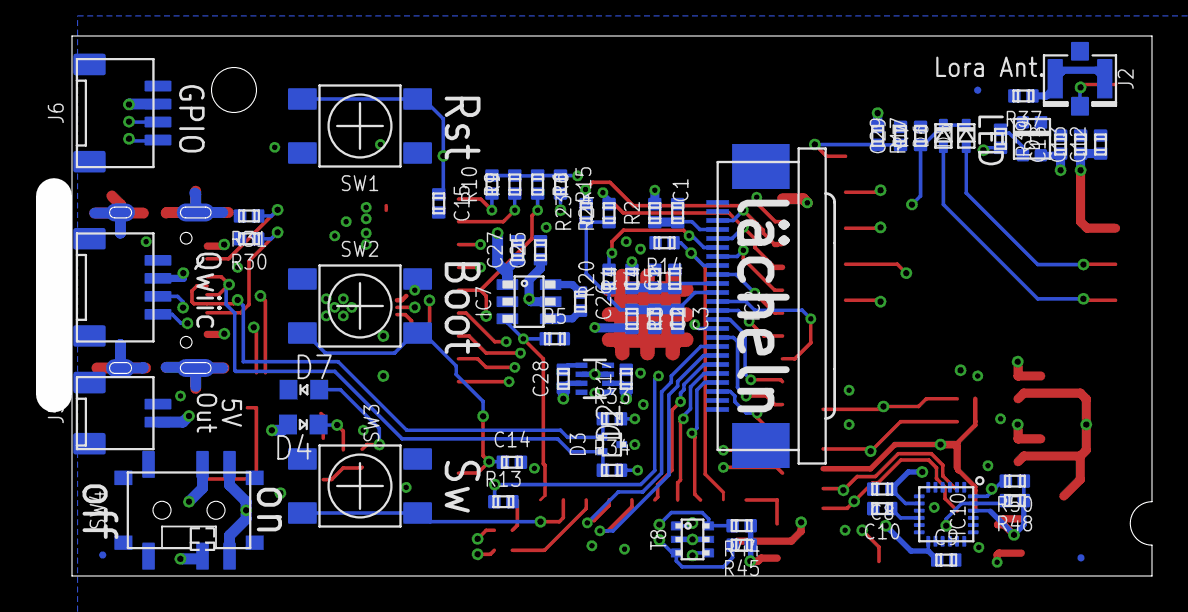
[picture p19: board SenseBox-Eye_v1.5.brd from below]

Board: 4 copper layers, 61.0 x 30.0 mm, 111 parts (66 on the bottom side), 74 nets.

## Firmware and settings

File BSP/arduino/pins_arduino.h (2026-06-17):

#ifndef Pins_Arduino_h
#define Pins_Arduino_h

#include <stdint.h>

#define USB_VID          0x303A
#define USB_PID          0x82D1
#define USB_MANUFACTURER "senseBox"
#define USB_PRODUCT      "Eye"
#define USB_SERIAL       ""  // Empty string for MAC address

// Default USB FirmwareMSC Settings
#define USB_FW_MSC_VENDOR_ID        "senseBox"     // max 8 chars
#define USB_FW_MSC_PRODUCT_ID       "Eye"  // max 16 chars
#define USB_FW_MSC_PRODUCT_REVISION "1.4"      // max 4 chars
#define USB_FW_MSC_VOLUME_NAME      "senseBox_Eye"     // max 11 chars
#define USB_FW_MSC_SERIAL_NUMBER    0x00000000

#define PIN_RGB_LED 45  // RGB LED
#define RGBLED_PIN  45  // RGB LED
#define PIN_LED     45
#define RGBLED_NUM  1  // number of RGB LEDs

static const uint8_t LED_BUILTIN = PIN_RGB_LED;
#define BUILTIN_LED LED_BUILTIN
#define LED_BUILTIN LED_BUILTIN  // allow #ifdef LED_BUILTIN

// =============================================
// I2C (QWIIC)
// =============================================
#define PIN_WIRE_SDA 2
#define PIN_WIRE_SCL 1

static const uint8_t SDA = PIN_WIRE_SDA;
static const uint8_t SCL = PIN_WIRE_SCL;

// =============================================
// SPI
// =============================================
#define PIN_SPI_MOSI 38
#define PIN_SPI_MISO 40
#define PIN_SPI_SCK  39
#define PIN_SPI_SS   41

static const uint8_t MOSI = PIN_SPI_MOSI;
static const uint8_t MISO = PIN_SPI_MISO;
static const uint8_t SCK  = PIN_SPI_SCK;
static const uint8_t SS   = PIN_SPI_SS;


// IO Pins
#define PIN_IO14 14
static const uint8_t A14 = PIN_IO14;  // Analog
static const uint8_t D14 = PIN_IO14;  // Digital
static const uint8_t T14 = PIN_IO14;  // Touch

#define PIN_IO48 48
static const uint8_t A48 = PIN_IO48;  // Analog
static const uint8_t D48 = PIN_IO48;  // Digital
static const uint8_t T48 = PIN_IO48;  // Touch

// Button
#define PIN_BUTTON 21
#define BUTTON 21

// =============================================
// SD Card
// =============================================
// SD shares the SPI bus — CS, detect switch, enable are SD-specific
#define PIN_SD_CS     41
#define PIN_SD_SW     42
#define PIN_SD_ENABLE 3
#define SD_CS    PIN_SD_CS
#define SD_SW    PIN_SD_SW
#define SD_ENABLE PIN_SD_ENABLE

// USB
#define PIN_USB_DM 19 // DM = D Minus
#define PIN_USB_DN 19 // DN = D Negative (same as DM)
#define PIN_USB_DP 20
#define USB_DN PIN_USB_DN
#define USB_DP PIN_USB_DP

// =============================================
// Camera
// =============================================
#define PWDN_GPIO_NUM  46
#define RESET_GPIO_NUM -1
#define XCLK_GPIO_NUM  15
#define SIOD_GPIO_NUM  4
#define SIOC_GPIO_NUM  5
#define Y9_GPIO_NUM    16
#define Y8_GPIO_NUM    17
#define Y7_GPIO_NUM    18
#define Y6_GPIO_NUM    12
#define Y5_GPIO_NUM    10
#define Y4_GPIO_NUM    8
#define Y3_GPIO_NUM    9
#define Y2_GPIO_NUM    11
#define VSYNC_GPIO_NUM 6
#define HREF_GPIO_NUM  7
#define PCLK_GPIO_NUM  13

// Schematics
#define CAM_PWDN  46
#define CAM_RESET -1
#define CAM_XMCLK   15
#define CAM_SDA    4
#define CAM_SCL    5
#define CAM_Y9     16
#define CAM_Y8     17
#define CAM_Y7     18
#define CAM_Y6     12
#define CAM_Y5     10
#define CAM_Y4     8
#define CAM_Y3     9
#define CAM_Y2     11
#define CAM_VSYNC  6
#define CAM_HREF   7
#define CAM_PCLK   13

    
// =============================================
// LoRa
// =============================================
#define PIN_LORA_CS 43
#define PIN_LORA_INT 44
#define LORA_CS    PIN_LORA_CS
#define LORA_INT   PIN_LORA_INT

#endif /* Pins_Arduino_h */

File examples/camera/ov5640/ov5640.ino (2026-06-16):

#include "esp_camera.h"
#include <Wire.h>
#include <Adafruit_GFX.h>
#include <Adafruit_SSD1306.h>
#include "soc/soc.h"
#include "soc/rtc_cntl_reg.h"
#include "driver/rtc_io.h"
#include "camera_pins.h"
#include "FS.h"
#include "SD.h"
#include "SPI.h"
#include "driver/rtc_io.h"
#include <EEPROM.h>

#define SW_BUTTON 21

#define EEPROM_SIZE 1

// Pin definition for SD Card
#define VSPI_MISO   40
#define VSPI_MOSI   38
#define VSPI_SCLK   39
#define VSPI_SS     41
#define SD_ENABLE   48
SPIClass sdspi = SPIClass();

int pictureNumber = 0;
camera_fb_t * fb = NULL;

#define PIN_QWIIC_SDA 2
#define PIN_QWIIC_SCL 1

#define SCREEN_WIDTH 128
#define SCREEN_HEIGHT 64
#define OLED_RESET -1

Adafruit_SSD1306 display(SCREEN_WIDTH, SCREEN_HEIGHT, &Wire, OLED_RESET);

uint8_t* jpegBuf = nullptr;
size_t jpegLen = 0;

void deleteAllFromSD(fs::FS &fs, const char * dirname) {
  File root = fs.open(dirname);
  if (!root || !root.isDirectory()) {
    Serial.println("Failed to open directory for deletion");
    return;
  }

  File file = root.openNextFile();
  while (file) {
    String path = String(dirname) + "/" + file.name();
    if (file.isDirectory()) {
      file.close();
      deleteAllFromSD(fs, path.c_str());
      fs.rmdir(path.c_str());
      Serial.printf("Removed folder: %s\n", path.c_str());
    } else {
      file.close();
      fs.remove(path.c_str());
      Serial.printf("Removed file: %s\n", path.c_str());
    }
    file = root.openNextFile();
  }
}

void setup() {
  pinMode(SW_BUTTON, INPUT_PULLUP);
  Wire.begin(PIN_QWIIC_SDA,PIN_QWIIC_SCL);
  Serial.begin(115200);
  delay(1500);

  // Init OLED
  display.begin(SSD1306_SWITCHCAPVCC, 0x3D);
  display.setRotation(2);
  display.display();
  delay(100);
  display.clearDisplay();
  display.setTextSize(1);
  display.setTextColor(WHITE);
  display.setCursor(0, 0);
  display.println("Initializing...");
  display.display();

  // Camera config
  camera_config_t config;
  config.ledc_channel = LEDC_CHANNEL_0;
  config.ledc_timer = LEDC_TIMER_0;
  config.pin_d0 = Y2_GPIO_NUM;
  config.pin_d1 = Y3_GPIO_NUM;
  config.pin_d2 = Y4_GPIO_NUM;
  config.pin_d3 = Y5_GPIO_NUM;
  config.pin_d4 = Y6_GPIO_NUM;
  config.pin_d5 = Y7_GPIO_NUM;
  config.pin_d6 = Y8_GPIO_NUM;
  config.pin_d7 = Y9_GPIO_NUM;
  config.pin_xclk = XCLK_GPIO_NUM;
  config.pin_pclk = PCLK_GPIO_NUM;
  config.pin_vsync = VSYNC_GPIO_NUM;
  config.pin_href = HREF_GPIO_NUM;
  config.pin_sccb_sda = SIOD_GPIO_NUM;
  config.pin_sccb_scl = SIOC_GPIO_NUM;
  config.pin_pwdn = PWDN_GPIO_NUM;
  config.pin_reset = RESET_GPIO_NUM;
  config.xclk_freq_hz = 20000000;
  config.pixel_format = PIXFORMAT_GRAYSCALE;
  config.frame_size = FRAMESIZE_96X96; // Small grayscale image
  config.jpeg_quality = 12;
  config.fb_count = 1;
  config.fb_location = CAMERA_FB_IN_PSRAM;
  config.grab_mode = CAMERA_GRAB_WHEN_EMPTY;

  // Initialize camera
  Serial.println("Init camera...");
  esp_err_t err = esp_camera_init(&config);
  if (err != ESP_OK) {
    Serial.printf("Camera init failed: 0x%x", err);
    display.println("Camera init failed!");
    display.display();
    return;
  }

  // Init SD Card
  Serial.println("Starting SD Card");
  delay(3);
  pinMode(SD_ENABLE, OUTPUT);
  digitalWrite(SD_ENABLE, LOW);

  sdspi.begin(VSPI_SCLK, VSPI_MISO, VSPI_MOSI, VSPI_SS);
  if (!SD.begin(VSPI_SS, sdspi)) {
    Serial.println("Card Mount Failed");
    return;
  }

  uint8_t cardType = SD.cardType();
  if (cardType == CARD_NONE) {
    Serial.println("No SD card attached");
    return;
  }

  EEPROM.begin(EEPROM_SIZE);
  pictureNumber = EEPROM.read(0) + 1;

  Serial.println("Wiping SD card...");
  deleteAllFromSD(SD,"/");
}

void loop() {
  // Capture image
  camera_fb_t *fb = esp_camera_fb_get();
  if (!fb) {
    Serial.println("Capture failed");
    display.println("Capture failed!");
    display.display();
    return;
  }

  // Prepare to draw
  display.clearDisplay();

  const int srcWidth = 96;
  const int srcHeight = 96;
  const int targetHeight = 64;
  const int targetWidth = 64;
  const int xOffset = (SCREEN_WIDTH - targetWidth) / 2;  // 32

  // Simple nearest-neighbor downscaling from 96x96 -> 64x64
  for (int y = 0; y < targetHeight; y++) {
    for (int x = 0; x < targetWidth; x++) {
      // Map target (x, y) to source (sx, sy)
      int sx = x * srcWidth / targetWidth;
      int sy = y * srcHeight / targetHeight;
      uint8_t pixel = fb->buf[sy * srcWidth + sx];

      if (pixel > 128) {
        display.drawPixel(x + xOffset, y, WHITE);
      } else {
        display.drawPixel(x + xOffset, y, BLACK);
      }
    }
  }

  display.display();
  esp_camera_fb_return(fb);

  // Button press: switch to RGB565, capture, save, switch back
  if (digitalRead(SW_BUTTON) == LOW) {
    if (!switchCameraFormat(PIXFORMAT_RGB565, FRAMESIZE_WQXGA)) { // 2560x1600
      Serial.println("Failed to switch to RGB565");
      return;
    }

    // init camera
    fb = esp_camera_fb_get();
    esp_camera_fb_return(fb);
    delay(50);

    // take actual picture
    fb = esp_camera_fb_get();

    if (fb && fb->format == PIXFORMAT_RGB565) {
      String filename = "/image" + String(pictureNumber) + ".jpg";
      // convert RGB565 to jpg
      if (frame2jpg(fb, 90, &jpegBuf, &jpegLen)) {
        File file = SD.open(filename, FILE_WRITE);
        if (file) {
          file.write(jpegBuf, jpegLen);
          file.close();
          Serial.println("Saved JPEG to SD: " + filename);
          pictureNumber++;
          EEPROM.write(0, pictureNumber);
          EEPROM.commit();
        }
        free(jpegBuf);
        jpegBuf = nullptr;
      }

      esp_camera_fb_return(fb);
    }

    // Reinitialize back to grayscale for OLED
    if (!switchCameraFormat(PIXFORMAT_GRAYSCALE, FRAMESIZE_96X96)) {
      Serial.println("Failed to switch back to GRAYSCALE");
      return;
    }

    delay(500); // prevent repeated triggers
  }
}

bool switchCameraFormat(pixformat_t format, framesize_t frame_size) {
  camera_config_t config;
  config.ledc_channel = LEDC_CHANNEL_0;
  config.ledc_timer = LEDC_TIMER_0;
  config.pin_d0 = Y2_GPIO_NUM;
  config.pin_d1 = Y3_GPIO_NUM;
  config.pin_d2 = Y4_GPIO_NUM;
  config.pin_d3 = Y5_GPIO_NUM;
  config.pin_d4 = Y6_GPIO_NUM;
  config.pin_d5 = Y7_GPIO_NUM;
  config.pin_d6 = Y8_GPIO_NUM;
  config.pin_d7 = Y9_GPIO_NUM;
  config.pin_xclk = XCLK_GPIO_NUM;
  config.pin_pclk = PCLK_GPIO_NUM;
  config.pin_vsync = VSYNC_GPIO_NUM;
  config.pin_href = HREF_GPIO_NUM;
  config.pin_sccb_sda = SIOD_GPIO_NUM;
  config.pin_sccb_scl = SIOC_GPIO_NUM;
  config.pin_pwdn = PWDN_GPIO_NUM;
  config.pin_reset = RESET_GPIO_NUM;
  config.xclk_freq_hz = 20000000;
  config.pixel_format = format;
  config.frame_size = frame_size;
  config.jpeg_quality = 10;
  config.fb_count = 1; // 2 would take up more space in the RAM
  config.fb_location = CAMERA_FB_IN_PSRAM;
  config.grab_mode = CAMERA_GRAB_LATEST;

  // to suppress error messages when switching camera profile
  esp_log_level_set("gdma", ESP_LOG_NONE);
  
  esp_camera_deinit();
  esp_log_level_set("gdma", ESP_LOG_WARN);
  return esp_camera_init(&config) == ESP_OK;
}

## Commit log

2025-03-24 add schematics
2025-03-24 add camerawebserver example
2025-03-24 i2c-scanner and vl53l8cx example
2025-03-25 add brd and sch
    [SenseBox-Eye_v1.0.brd, SenseBox-Eye_v1.0.sch]
2025-03-25 add button example
2025-03-25 add camera-display example
2025-03-26 add i2c chain example
2025-03-26 add boot button example
2025-03-26 add mark-ups for BSP
    [partitions-8MB-tinyuf2.csv]
2025-03-27 add alternative pin name
2025-04-01 add led-matrix example
2025-04-02 add camera sd-card example
2025-04-08 add v1.1 schematics and rename
    [senseBox-Eye_v1.0.brd, senseBox-Eye_v1.0.sch, senseBox-Eye_v1.1.brd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]
2025-04-08 mention antenna
2025-04-08 update antenna info
2025-04-10 add tested cameras
2025-04-14 surpress error messages when switching camera profile
    [ov7725.ino]
2025-04-16 16mb flash instead of 8
    [partitions-16MB-tinyuf2.csv]
2025-04-29 new schematics
    [SenseBox-Eye_v1.2.brd, SenseBox-Eye_v1.2.sch]
2025-04-29 update v1.2 schematics
    [SenseBox-Eye_V12.brd, SenseBox-Eye_V12.sch]
2025-05-12 add ref to arduino-esp32 core fix
2025-05-15 add readme about ov5640 and esp32-camera driver
2025-05-22 ref camera settings tutorial
2025-05-26 add CameraWebServer with edge impulse
    [partitions.csv]
2025-06-11 warm up camera before actual capture
2025-06-11 update RGB_LED pin
2025-06-11 add vl53l8cx + LED-matrix example
2025-06-23 update camera pins
2025-07-10 check if sd card inserted with SW Pin
2025-07-10 update led pin
2025-07-10 use custom partition and enable psram
    [partitions.csv]
2026-03-05 add acceleration sensor examples
2026-03-10 update BSP
    [partitions-16MB-tinyuf2.csv]
2026-03-16 add 5V-out example
2026-06-16 update button pin in examples
2026-06-16 fix led-matrix sketch
2026-06-16 update cameraWebServer example
2026-06-16 update 5V pin
2026-09-22 add BOM to v1.5 (selfmade, not watterott)
    [SenseBox-MCU-Eye-v1.5_BOM.xlsx]
